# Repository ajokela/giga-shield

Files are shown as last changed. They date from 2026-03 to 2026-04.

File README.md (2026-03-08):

# Arduino Giga R1 WiFi Shield - Driven Level Shifter Redesign

## Overview

This is a redesigned shield/daughter board for the **Arduino Giga R1 WiFi** that replaces the original TXB0108PW auto-sensing bidirectional level translators with **SN74LVC8T245PW** driven (direction-controlled) level shifters.

The board provides 72 channels of 3.3V-to-5V level shifting across 9 ICs, mapping the Giga's 3.3V GPIO signals to 5V-compatible headers suitable for interfacing with retro hardware such as the Z80 CPU via a RetroShield.

## Why the Redesign

The original board used **TXB0108PW** auto-sensing bidirectional level translators. While convenient (no direction pin needed), the auto-sensing mechanism fails during Z80 bus cycles when signals are tri-stated. During these periods, the TXB0108 cannot determine the correct drive direction, causing the Arduino to be completely blind to certain Z80 execution states. This makes reliable bus monitoring and intervention impossible.

The **SN74LVC8T245PW** is a driven (explicit direction control) 8-bit dual-supply bus transceiver. The DIR pin explicitly sets the translation direction:
- **DIR LOW** = A-port to B-port (3.3V to 5V)
- **DIR HIGH** = B-port to A-port (5V to 3.3V)

This eliminates the ambiguity during tri-state periods and gives the Arduino full control over when it's reading vs. writing the bus.

## Board Specifications

| Parameter | Value |
|---|---|
| Dimensions | 155mm x 90mm |
| Layers | 2 (top + bottom copper) |
| Level Shifters | 9x SN74LVC8T245PW (TSSOP-24) |
| Decoupling Caps | 27x 0.1uF ceramic (0603) |
| DIR Pull-downs | 9x 10K resistor (0603) |
| Connectors | 10x pin headers (J1-J10) + 1x DIR control (J11) |
| Mounting Holes | 4x 3.2mm |
| Traces | 1843 |
| Vias | 158 |

## Signal Mapping

Each SN74LVC8T245PW translates 8 signals between the Giga's 3.3V domain (A-port) and the 5V headers (B-port).

### U1 - SCL/SDA/D9-D13
| A-Port (3.3V) | B-Port (5V) | Function |
|---|---|---|
| SCL1 | PB6 | I2C Clock |
| SDA1 | PH12 | I2C Data |
| AREF_3V3 | AREF | Analog Reference |
| D13 | PH6 | Digital 13 |
| D12 | PJ11 | Digital 12 |
| D11 | PJ10 | Digital 11 |
| D10 | PK1 | Digital 10 |
| D9 | PB9 | Digital 9 |

### U2 - Analog A0-A7
| A-Port (3.3V) | B-Port (5V) | Function |
|---|---|---|
| PC4 | A0 | Analog 0 |
| PC5 | A1 | Analog 1 |
| PB0 | A2 | Analog 2 |
| PB1 | A3 | Analog 3 |
| PC3 | A4 | Analog 4 |
| PC2 | A5 | Analog 5 |
| PC0 | A6 | Analog 6 |
| PA0 | A7 | Analog 7 |

### U3 - Digital D1-D8
| A-Port (3.3V) | B-Port (5V) | Function |
|---|---|---|
| D8 | PB8 | Digital 8 |
| D7 | PB4 | Digital 7 |
| D6 | PD13_5V | Digital 6 |
| D5 | PA7 | Digital 5 |
| D4 | PJ8 | Digital 4 |
| D3 | PA2 | Digital 3 |
| D2 | PA3 | Digital 2 |
| D1 | PA9 | Digital 1 |

### U4 - Analog A8-A11, DAC, CAN
| A-Port (3.3V) | B-Port (5V) | Function |
|---|---|---|
| PC2_C | A8 | Analog 8 |
| PC3_C | A9 | Analog 9 |
| PA1_C | A10 | Analog 10 |
| PA0_C | A11 | Analog 11 |
| PA4 | DAC0 | DAC Channel 0 |
| PA5 | DAC1 | DAC Channel 1 |
| PB5 | CAN_RX | CAN Bus RX |
| PB13 | CAN_TX | CAN Bus TX |

### U5 - Digital D0, D14-D20
| A-Port (3.3V) | B-Port (5V) | Function |
|---|---|---|
| D0 | PB7 | Digital 0 |
| D14 | PG14 | Digital 14 |
| D15 | PC7 | Digital 15 |
| D16 | PH13 | Digital 16 |
| D17 | PI9 | Digital 17 |
| D18 | PD5 | Digital 18 |
| D19 | PD6 | Digital 19 |
| D20 | PB11 | Digital 20 |

### U6 - Digital Even D22-D36
| A-Port (3.3V) | B-Port (5V) | Function |
|---|---|---|
| D22 | PJ12 | Digital 22 |
| D24 | PG12 | Digital 24 |
| D26 | PJ14 | Digital 26 |
| D28 | PJ15 | Digital 28 |
| D30 | PK3 | Digital 30 |
| D32 | PK4 | Digital 32 |
| D34 | PK5 | Digital 34 |
| D36 | PK6 | Digital 36 |

### U7 - Digital Odd D37-D51
| A-Port (3.3V) | B-Port (5V) | Function |
|---|---|---|
| D37 | PJ6 | Digital 37 |
| D39 | PI14 | Digital 39 |
| D41 | PK7 | Digital 41 |
| D43 | PI10 | Digital 43 |
| D45 | PI13 | Digital 45 |
| D47 | PB2 | Digital 47 |
| D49 | PE4 | Digital 49 |
| D51 | PE5 | Digital 51 |

### U8 - Digital Odd D21-D35
| A-Port (3.3V) | B-Port (5V) | Function |
|---|---|---|
| D21 | PH4 | Digital 21 |
| D23 | PG13 | Digital 23 |
| D25 | PJ0 | Digital 25 |
| D27 | PJ1 | Digital 27 |
| D29 | PJ2 | Digital 29 |
| D31 | PJ3 | Digital 31 |
| D33 | PJ4 | Digital 33 |
| D35 | PJ5 | Digital 35 |

### U9 - Digital Even D38-D52
| A-Port (3.3V) | B-Port (5V) | Function |
|---|---|---|
| D38 | PJ7 | Digital 38 |
| D40 | PE6 | Digital 40 |
| D42 | PI15 | Digital 42 |
| D44 | PG10 | Digital 44 |
| D46 | PH15 | Digital 46 |
| D48 | PK0 | Digital 48 |
| D50 | PI11 | Digital 50 |
| D52 | PK2 | Digital 52 |

## DIR Control (J11)

The J11 header provides per-shifter direction control. Each pin corresponds to one SN74LVC8T245PW's DIR input. A **10K pull-down resistor** on each DIR line defaults the direction to **A-to-B (3.3V to 5V)**.

| J11 Pin | Signal | Controls |
|---|---|---|
| 1 | DIR_U1 | U1 (SCL/SDA/D9-D13) |
| 2 | DIR_U2 | U2 (A0-A7) |
| 3 | DIR_U3 | U3 (D1-D8) |
| 4 | DIR_U4 | U4 (A8-A11/DAC/CAN) |
| 5 | DIR_U5 | U5 (D0/D14-D20) |
| 6 | DIR_U6 | U6 (Even D22-D36) |
| 7 | DIR_U7 | U7 (Odd D37-D51) |
| 8 | DIR_U8 | U8 (Odd D21-D35) |
| 9 | DIR_U9 | U9 (Even D38-D52) |
| 10 | GND | Ground reference |

To change a shifter's direction to **B-to-A (5V to 3.3V)**, drive the corresponding J11 pin HIGH (3.3V). This is done by running jumper wires from available Giga GPIO pins to the J11 header. Software then controls direction by toggling those GPIOs.

## Connectors

| Ref | Type | Pins | Location | Function |
|-----|---|---|---|---|
| J1 | 1x8 | 8 | Bottom edge | Giga 3.3V analog header |
| J2 | 1x10 | 10 | Top edge | Giga 3.3V header (power/analog ext) |
| J3 | 1x8 | 8 | Bottom edge | Giga 3.3V digital D1-D8 |
| J4 | 1x8 | 8 | Top edge | Giga 3.3V digital SCL/SDA/D9-D13 |
| J5 | 1x26 | 26 | Bottom edge | 5V analog header (J_ANALOG) |
| J6 | 1x8 | 8 | Bottom edge | Giga 3.3V digital D0/D14-D20 |
| J7 | 1x8 | 8 | Top edge | Giga 3.3V D21 + misc |
| J8 | 1x26 | 26 | Top edge | 5V digital header (J_DIGITAL) |
| J9 | 2x18 | 36 | Right side | 3.3V side connector (JSIDE) |
| J10 | 2x18 | 36 | Right side | 5V side connector (JSIDE_5V) |
| J11 | 1x10 | 10 | Center-left | DIR control header |

## Design Toolchain

The original board was designed in **KiCad 9.0** (file version 20241229). Since pcb-rnd 3.1.4 cannot read KiCad 9.0 files (version too new), the board was rebuilt from scratch using a Python generator script.

### Tools Used

| Tool | Version | Purpose |
|---|---|---|
| KiCad | 9.0.6 | Original design source, position/netlist reference |
| pcb-rnd | 3.1.4 | PCB format, DSN export, gerber/PNG export |
| Freerouting | 1.9.0 | Specctra-based autorouter |
| Python | 3.x | Board generator script (`build_giga_shield.py`) |

### Build Pipeline

1. **`build_giga_shield.py`** generates `giga_shield.pcb` with all components placed, footprints defined, and netlist specified in pcb-rnd native format
2. **pcb-rnd** exports the unrouted board to Specctra DSN format (`giga_shield.dsn`)
3. **Freerouting** reads the DSN, autoroutes all nets, and outputs a Specctra session file (`giga_shield.ses`)
4. **`ses_to_pcb.py`** imports the routed traces from the SES file back into the PCB
5. **pcb-rnd** exports final gerbers, drill files, and photo-realistic PNG renderings

### Key Implementation Details

- Component positions were extracted from the original KiCad PCB and translated from KiCad's coordinate origin (x=106mm, y=30.5mm) to pcb-rnd's (0,0) origin using the `kpos()` function
- All 1x pin headers are rotated 90 degrees to run horizontally along the board edges, matching the original KiCad layout (the Arduino Giga shield form factor has edge-parallel headers)
- TSSOP-24 footprints are generated programmatically with correct 0.65mm pitch, 6.4mm pad-to-pad span
- The SN74LVC8T245PW pin mapping was carefully verified against the datasheet: pins 1-12 on the left (DIR, A1-A4, GND, A5-A8, OE#, GND) and pins 13-24 on the right (B8-B5, VCCB, B4-B1, VCCA, VCCA, VCCB)
- OE# (pin 11) is tied to GND on all shifters (always enabled)
- Each shifter has two 0.1uF decoupling caps: one on VCCA (3.3V) and one on VCCB (5V)
- An additional 9 decoupling caps are placed along the bottom edge for power rail filtering

## SN74LVC8T245PW vs TXB0108PW

| Feature | TXB0108PW (Original) | SN74LVC8T245PW (New) |
|---|---|---|
| Package | TSSOP-20 | TSSOP-24 |
| Channels | 8 | 8 |
| Direction | Auto-sensing | Explicit DIR pin |
| A-Port Voltage | 1.2V - 3.6V | 1.2V - 3.6V |
| B-Port Voltage | 1.65V - 5.5V | 1.65V - 5.5V |
| Max Data Rate | 100 Mbps | 380 Mbps |
| Tri-state Handling | Unreliable | Deterministic |
| Output Enable | OE (active low) | OE# (active low) |
| Extra Pins | None | DIR control |

## Files

| File | Description |
|---|---|
| `build_giga_shield.py` | Python script that generates the entire PCB from scratch |
| `giga_shield.pcb` | Final routed PCB in pcb-rnd format |
| `giga_shield.dsn` | Specctra DSN export for autorouting |
| `giga_shield.ses` | Specctra session file with routing solution |
| `giga_shield_bom.csv` | Bill of materials |
| `giga_shield_centroid.csv` | Pick-and-place centroid file (SMD components) |
| `giga_shield_gerbers.zip` | Production files (gerbers + BOM + centroid) |
| `giga_shield_top.png` | Photo-realistic top view rendering |
| `giga_shield_bottom.png` | Photo-realistic bottom view rendering |
| `sn74lvc8t245_pinout.txt` | SN74LVC8T245 pinout reference |
| `kicad_source/` | Original KiCad 9.0 design files (reference) |
| `kicad_source/AlexJ_bz_ArduinoGigaShield.kicad_pcb` | Original KiCad PCB |
| `kicad_source/AlexJ_bz_ArduinoGigaShield.kicad_sch` | Original KiCad schematic |
| `kicad_source/AlexJ_bz_ArduinoGigaShield.pdf` | Original schematic PDF |
| `kicad_source/giga_pos.csv` | Component positions exported from KiCad |
| `kicad_source/giga_netlist.d356` | IPC-D-356 netlist exported from KiCad |

## Board Renderings

### Top
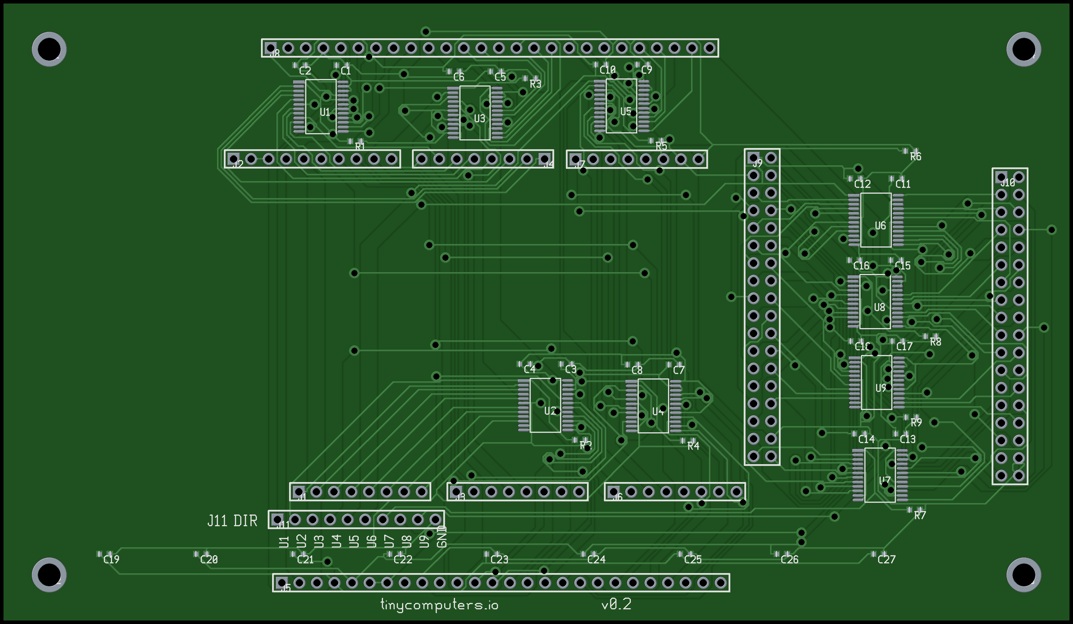
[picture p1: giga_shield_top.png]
Top View


### Bottom
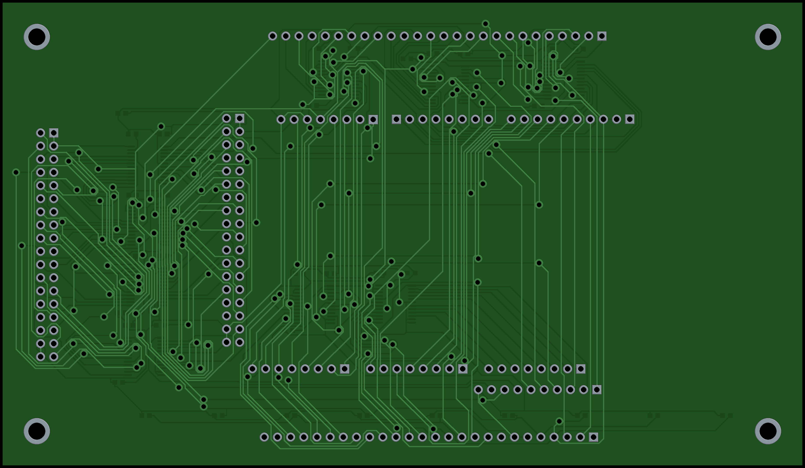
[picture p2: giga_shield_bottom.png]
Bottom View


## Development Notes

This section documents the full development process, including toolchain issues, format debugging, and workarounds encountered during the redesign.

### Starting Point

The original design (`AlexJ_bz_ArduinoGigaShield.kicad_pcb`) was created in **KiCad 9.0** (internal file version 20241229) with 9x TXB0108PW auto-sensing level shifters. The goal was to convert this to pcb-rnd format, swap in SN74LVC8T245PW driven shifters, and produce a fully routed production board.

### KiCad 9.0 to pcb-rnd Conversion Failure

pcb-rnd 3.1.4 includes an `io_kicad` plugin for reading KiCad files, but it only supports older KiCad versions. Attempting to open the KiCad 9.0 PCB produced:

```
unexpected layout version number (perhaps too new)
```

This was a hard blocker — there is no format converter from KiCad 9.0 to pcb-rnd.

### Extracting Data from KiCad

Since direct conversion was impossible, component positions and netlist data were extracted from KiCad using available tools:

1. **Component positions** were exported using `kicad-cli`:
   ```
   kicad-cli pcb export pos AlexJ_bz_ArduinoGigaShield.kicad_pcb -o giga_pos.csv
   ```

2. **Netlist/connectivity** was exported via IPC-D-356:
   ```
   kicad-cli pcb export ipc2581 ... -o giga_netlist.d356
   ```

3. **Signal mappings** (which Giga pin connects to which 5V header pin through which shifter) were extracted by parsing the KiCad schematic file (`AlexJ_bz_ArduinoGigaShield.kicad_sch`), which uses an s-expression format with positional net connections across hierarchical sheets.

### Building the Board from Scratch

With positions and netlist in hand, `build_giga_shield.py` was written to generate the entire pcb-rnd board programmatically. This script:

- Converts KiCad coordinates to pcb-rnd coordinates (KiCad origin at x=106mm, y=30.5mm; pcb-rnd at 0,0) using:
  ```python
  KX, KY = 106.0, 30.5
  def kpos(kx, ky):
      return (mm(kx - KX), mm(ky - KY))
  ```
- Generates TSSOP-24 footprints for the SN74LVC8T245PW (0.65mm pitch, 6.4mm pad-to-pad span, 24 pins with correct pin naming)
- Creates 0603 SMD footprints for decoupling caps and pull-down resistors
- Creates through-hole pin header footprints with rotation support
- Builds the complete netlist mapping all 72 signal channels across 9 shifters
- Outputs a valid pcb-rnd `.pcb` file

### pcb-rnd Format Debugging

Getting pcb-rnd to accept the generated file required solving several format issues. pcb-rnd's parser error messages were often unhelpful — errors in element definitions would sometimes be reported at a much later line (e.g., the outline layer starting at line 959).

**Issue 1: Element `"smd"` flag**

```
Element["smd" "TSSOP24" "U1" ...]
```
pcb-rnd rejected this with `Unknown flag: smd ignored`, which cascaded into a parse failure. The fix was to use an empty string for the first field:
```
Element["" "TSSOP24" "U1" ...]
```

**Issue 2: Bare `0` without unit suffix**

Mixed use of `0` and `0nm` in coordinate values caused silent parse errors:
```
Pin[0 0 1700000nm ...]    # WRONG - bare 0
Pin[0nm 0nm 1700000nm ...]  # CORRECT
```
All zero values needed the explicit `nm` suffix for consistency.

**Issue 3: Layer `Line[]` missing flags argument**

The `Line[]` entry inside Layer blocks requires 7 fields, but the generator was only outputting 6 (omitting the flags string):
```
Line[x1 y1 x2 y2 thickness clearance]           # WRONG - 6 fields
Line[x1 y1 x2 y2 thickness clearance "clearline"]  # CORRECT - 7 fields
```
The error was `syntax error, unexpected ']', expecting INTEGER or STRING`, which appeared at the outline layer rather than at the actual problematic line.

**Debugging technique: Binary search with file truncation**

Since pcb-rnd always reported the error at the same line regardless of where the actual issue was, a binary search approach was used — progressively truncating the file with `head -N` to isolate which section introduced the parse failure:
```
head -100 giga_shield.pcb > test.pcb && pcb-rnd -x png test.pcb  # OK → mounting holes fine
head -300 giga_shield.pcb > test.pcb && pcb-rnd -x png test.pcb  # OK → connectors fine
head -500 giga_shield.pcb > test.pcb && pcb-rnd -x png test.pcb  # OK → shifters fine
head -700 giga_shield.pcb > test.pcb && pcb-rnd -x png test.pcb  # OK → all elements fine
head -960 giga_shield.pcb > test.pcb && pcb-rnd -x png test.pcb  # FAIL → layers are the problem
```
This narrowed the issue to the Layer blocks, where the missing flags argument was found.

### Connector Rotation

The initial build placed all pin headers with pins extending downward (+Y). For the Arduino Giga shield form factor, the long 1x headers actually run horizontally along the board edges. Without rotation, J5 (1x26 at y=84mm) extended 63.5mm downward to y=148mm — well past the 90mm board edge. J11 (1x10 at y=75mm) similarly extended to y=98mm.

The fix involved:
1. Extracting rotation angles from the original KiCad PCB — all 1x headers had 90° or -90° rotation
2. Adding a `rot` parameter to `pin_header_element()` with a rotation transform:
   ```python
   def rotate(px, py):
       if rot == 90:     # KiCad 90° → pins extend in +X
           return (py, -px)
       elif rot == -90:  # KiCad -90° → pins extend in -X
           return (-py, px)
       return (px, py)
   ```
3. Applying rotation to both pin coordinates and element outlines

After rotation, all connectors fit within the board:
- J5 (1x26): x=[40.6, 104.1], y=84.2 — runs along the bottom edge
- J8 (1x26): x=[39.0, 102.5], y=6.8 — runs along the top edge
- J11 (1x10): x=[40.0, 62.9], y=75.0 — runs horizontally on the board

### Remote Toolchain

pcb-rnd is not readily available on macOS. All pcb-rnd operations (DSN export, gerber generation, PNG rendering) were performed on a remote Linux machine via SSH:

```bash
# Upload PCB
scp giga_shield.pcb alex@192.168.0.219:/tmp/

# Export DSN for autorouting
ssh alex@192.168.0.219 'cd /tmp && pcb-rnd -x dsn giga_shield.pcb'

# Export gerbers
ssh alex@192.168.0.219 'cd /tmp && pcb-rnd -x gerber giga_shield.pcb'

# Render photo-realistic PNG (600 DPI, green solder mask, gold plating)
ssh alex@192.168.0.219 'pcb-rnd -x png --dpi 600 --photo-mode --outfile top.png giga_shield.pcb'
ssh alex@192.168.0.219 'pcb-rnd -x png --dpi 600 --photo-mode --photo-flip-y --outfile bottom.png giga_shield.pcb'

# Download results
scp alex@192.168.0.219:/tmp/giga_shield.*.gbr .
scp alex@192.168.0.219:/tmp/top.png giga_shield_top.png
```

### Autorouting Pipeline

The routing pipeline uses Specctra DSN/SES interchange format as the bridge between pcb-rnd and Freerouting:

```
giga_shield.pcb → [pcb-rnd DSN export] → giga_shield.dsn
                                               ↓
                                    [Freerouting autorouter]
                                         (~55 minutes)
                                               ↓
giga_shield.pcb ← [ses_to_pcb.py]  ← giga_shield.ses
```

**Freerouting** (v1.9.0) is a Java-based Specctra autorouter:
```bash
java -jar freerouting-1.9.0.jar -de giga_shield.dsn -do giga_shield.ses -mp 60
```
The `-mp 60` flag sets 60 optimization passes. A typical run takes ~55 minutes and produces optimized routing with ~1843 traces and ~158 vias.

**`ses_to_pcb.py`** parses the Freerouting SES output and injects `Line[]` entries (traces) and `Via[]` entries into the pcb-rnd PCB file's Layer blocks.

**`strip_traces.py`** removes all routed traces and autorouted vias from a PCB file, leaving only components and netlist — used to prepare for re-routing after component moves. It identifies autorouted vias by their 914400nm pad size (the default from `ses_to_pcb.py`).

Both helper scripts originate from the [dual-z80](https://github.com/ajokela/dual-z80) project.

### Reproduction Steps

To rebuild the board from scratch:

```bash
# 1. Generate the unrouted PCB
python3 build_giga_shield.py giga_shield.pcb

# 2. Export DSN (on a machine with pcb-rnd installed)
pcb-rnd -x dsn giga_shield.pcb

# 3. Run Freerouting (~55 minutes)
java -jar freerouting-1.9.0.jar -de giga_shield.dsn -do giga_shield.ses -mp 60

# 4. Import routes back into PCB
python3 ses_to_pcb.py giga_shield.ses giga_shield.pcb

# 5. Export gerbers
pcb-rnd -x gerber giga_shield.pcb

# 6. Render board images
pcb-rnd -x png --dpi 600 --photo-mode --outfile giga_shield_top.png giga_shield.pcb
pcb-rnd -x png --dpi 600 --photo-mode --photo-flip-y --outfile giga_shield_bottom.png giga_shield.pcb
```

To re-route after component changes:
```bash
# Strip existing traces
python3 strip_traces.py giga_shield.pcb

# Then repeat steps 2-6 above
```

## License

BSD 3-Clause License

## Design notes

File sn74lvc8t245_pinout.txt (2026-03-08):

SN74LVC8T245PW (TSSOP-24) Pinout:
Pin 1:  1DIR    (Direction control: LOW=A→B, HIGH=B→A)
Pin 2:  A1
Pin 3:  A2
Pin 4:  A3
Pin 5:  A4
Pin 6:  GND
Pin 7:  A5
Pin 8:  A6
Pin 9:  A7
Pin 10: A8
Pin 11: 1OE#    (Output Enable, active LOW)
Pin 12: GND
Pin 13: B8
Pin 14: B7
Pin 15: B6
Pin 16: B5
Pin 17: VCCB    (5V side power)
Pin 18: B4
Pin 19: B3
Pin 20: B2
Pin 21: B1
Pin 22: VCCA    (3.3V side power)
Pin 23: VCCA
Pin 24: VCCB

TXB0108PW (TSSOP-20) Pinout (current):
Pin 1:  VCCA    (3.3V side power)
Pin 2:  A1
Pin 3:  A2
Pin 4:  A3
Pin 5:  A4
Pin 6:  A5
Pin 7:  A6
Pin 8:  A7
Pin 9:  A8
Pin 10: GND
Pin 11: OE      (Output Enable, active HIGH)
Pin 12: B8
Pin 13: B7
Pin 14: B6
Pin 15: B5
Pin 16: B4
Pin 17: B3
Pin 18: B2
Pin 19: B1
Pin 20: VCCB    (5V side power)

Key differences:
- SN74LVC8T245 has 24 pins (4 more: extra GND, extra VCC, DIR, split VCCA)
- DIR pin added (pin 1) - this is the key feature
- OE is active LOW on SN74LVC8T245 (vs active HIGH on TXB0108)
- A5-A8 shifted by one position due to extra GND at pin 6
- B-side pins similar but shifted
- Dual VCCA pins (22,23) and dual VCCB pins (17,24)

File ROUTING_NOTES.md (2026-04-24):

# Giga Shield v0.3: Routing Journey

Notes for a future blog post. Covers everything tried to get a fully-routed 6-layer level shifter board.

## The Board

Arduino Giga R1 WiFi shield with 10x SN74LVC8T245PW driven level shifters (TSSOP-24). Replaces the original TXB0108PW auto-sensing design, which fails during Z80 bus tri-state periods. 155mm x 90mm, 80 channels of 3.3V/5V level shifting, 161 nets, 39 SMD components, 10+ through-hole connectors.

## The Core Problem: GND

The board has 72 GND pads across 10 TSSOP-24 ICs (pins 6, 11, 12 on each), 29 decoupling caps, and 10 pull-down resistors. In a normal KiCad workflow, you'd route signals and then flood the board with a GND copper pour. Freerouting (the open-source Specctra autorouter) cannot do copper pours. It treats every net, including GND, as point-to-point traces.

The TSSOP-24 package makes this worse. At 0.65mm pitch, there's only ~0.25mm between pad edges. A via needs ~0.9mm diameter (drill + annular ring + clearance). There is physically no room to place a via next to a TSSOP-24 GND pad without violating DRC. Freerouting reports "via mask not found for net" and leaves GND connections unrouted.

## The Toolchain

The board was designed entirely in Python. `build_giga_shield.py` generates a pcb-rnd native `.pcb` file from scratch, with all component positions, footprints, and netlists defined programmatically. Component positions were extracted from an earlier KiCad 9.0 design, but pcb-rnd 3.1.4 can't read KiCad 9.0 files, so everything was regenerated.

The routing pipeline:
```
build_giga_shield.py -> giga_shield.pcb
                           |
                    pcb-rnd DSN export
                           |
                    giga_shield.dsn
                           |
                    Freerouting 1.9.0
                           |
                    giga_shield.ses
                           |
                    ses_to_pcb.py -> routed giga_shield.pcb
```

pcb-rnd runs on a remote Linux machine (10.1.1.27, Ryzen AI MAX+ 395) via SSH since it's not available on macOS.

## Attempt 1: 2-Layer with Freerouting

The simplest approach. Exclude GND from routing, let freerouting handle all signal and power nets on 2 layers, then add GND connections afterward.

**Config:**
```python
POWER_NETS = {'GND', 'VIN'}  # excluded from routing
```

Freerouting 1.9.0 with `-mp 100` (100 optimization passes). Single run: ~55 minutes. Result: 6 unrouted nets on the best run. The remaining 6 were always signal traces boxed in by other routes with no path to their destination.

**Verdict:** Close but not clean. 6 unrouted is 6 too many for production.

## Attempt 2: Manual GND Post-Processing (add_gnd.py)

Wrote a script to add GND after routing. Strategy:
1. Calculate exact GND pad positions from component geometry
2. Place a via near each SMD GND pad (offset ~0.5mm to avoid other pads)
3. Connect all vias on the bottom layer using a Minimum Spanning Tree (Prim's algorithm)

The MST approach minimizes total trace length while connecting all 72+ GND points. IC GND pads get vias offset to the left (away from IC body), cap/resistor pads get vias offset downward.

**Problem:** The vias still couldn't fit in the 0.65mm pitch gaps between TSSOP-24 pads. Even with the offset, they collided with adjacent signal pads. The script produced a connected GND network but with DRC violations everywhere.

**Verdict:** Clever but geometry wins. Can't squeeze a 0.9mm via into a 0.25mm gap.

## Attempt 3: Copper Pour + Stitching Vias (add_pours.py)

Instead of point-to-point GND traces, add a full copper polygon on the bottom layer and stitch it with vias:
- Full-board GND polygon on Layer 2 with 0.5mm edge margin
- 30 vias near IC GND pads (1.5mm offset from pad center)
- 20 vias near cap GND pads (1.2mm offset)
- Grid of stitching vias every 15mm across the board

**Problem:** pcb-rnd polygons in the native format don't have net assignment in the way that matters for DRC. The polygon existed but wasn't treated as part of the GND net by the autorouter or DRC checker. The GND pads were still electrically floating.

**Verdict:** pcb-rnd's polygon support isn't designed for this workflow.

## Attempt 4: 4-Layer Board

Added two inner layers: one for GND plane, one for power (+3V3/+5V). This is the "standard" solution for dense SMD boards.

**Config:**
```python
# 4 layers: top(1), GND(2), power(3), bottom(4), outline(5)
out.append('Groups("1,c:2:3:4,s:5")')
```

Freerouting still couldn't use the inner GND layer as a plane. It only does point-to-point routing. The extra layers gave more room for signal traces, but the fundamental GND problem remained. Best result: still 5-6 unrouted.

**Verdict:** More layers don't help when the tool can't do planes.

## Attempt 5: 6-Layer Board

Six copper layers: top, GND, signal, signal, GND, bottom.

Same fundamental limitation. Freerouting had more routing channels but still couldn't handle GND as a plane. Best result with 6 layers: 5 unrouted.

**Verdict:** Diminishing returns. The problem is the tool, not the layer count.

## Attempt 6: Massively Parallel Routing

The insight: freerouting converges to a local optimum. Different net ordering in the DSN file produces different initial routing solutions, which converge to different local optima. If you run enough parallel jobs, one might find the global optimum (0 unrouted).

### Net Shuffling (shuffle_dsn.py)

Wrote a script to generate N copies of the DSN file with randomized net ordering:
```python
random.seed(i * 31337 + 42)  # deterministic but different per copy
random.shuffle(shuffled_nets)
```

Generated 128+ shuffled copies. Each one routes nets in a different order, exploring a different region of the solution space.

### Infrastructure: 3 Machines

- **Local Mac** (M3 Max): 8 parallel jobs
- **10.1.1.24** (64-core, 4x Tesla P40): 64 parallel jobs
- **10.1.1.27** (32-core, Ryzen AI MAX+ 395): 64 parallel jobs

Total: 128+ simultaneous freerouting instances.

### Deployment Hurdles

**Java version mismatch.** Freerouting 1.9.0 was compiled targeting Java 24 (class file version 68.0). The servers had Java 21 (max class version 65.0). Error: `UnsupportedClassVersionError: class file version 68.0`. Fixed by modifying `freerouting/build.gradle`:
```groovy
// Changed from VERSION_24 to VERSION_21
sourceCompatibility = JavaVersion.VERSION_21
targetCompatibility = JavaVersion.VERSION_21
// Commented out java.toolchain block
```
Then rebuilt: `./gradlew executableV19Jar --no-configuration-cache`

**Gradle toolchain error.** `JvmVendorSpec IBM_SEMERU field not found` when building. Fixed by commenting out the entire `java.toolchain` block.

**X11 headless requirement.** Freerouting's GUI code initializes even in batch mode (`-de`, `-do` flags). On headless servers: `HeadlessException: No X11 DISPLAY variable was set`. Fix: install full JRE (`openjdk-21-jre`, not `-headless`) and use `xvfb-run -a` or a shared Xvfb display.

Two scripts for this:
- `run_batch.sh`: Single shared `Xvfb :99` display for all 64 jobs
- `run_batch_xvfb.sh`: `xvfb-run -a` per job (auto-allocated display numbers, more robust)

**Disk space on 10.1.1.27.** 1.9TB disk was at 100% (191GB old logs, large TTS wav files from previous projects). Had to clean up before jobs could write output.

**scp brace expansion.** `scp shuffled_runs/run_{000..031}.dsn user@host:` doesn't work on macOS zsh (brace expansion happens before scp processes the argument). Used `scp shuffled_runs/*.dsn` instead.

### Results: 2-Layer Parallel

Best result across 128 runs: **6 unrouted**. Multiple runs hit 6, none hit 0. The 2-layer board appears to have a hard floor around 6 unrouted nets.

### Results: 6-Layer Parallel

Best result: **5 unrouted**. Marginal improvement but still not clean.

### Freerouting 2.1.0: A Regression

Tried the newer Freerouting v2.1.0 hoping for better results. It was dramatically worse: **152+ unrouted** after 250 passes on the same 2-layer board where v1.9.0 hit 6. Immediately went back to v1.9.0.

**Verdict:** Massive parallelism finds better solutions but can't break through the fundamental floor. The problem is GND routing in TSSOP-24 pitch, and no amount of net shuffling fixes that.

## Attempt 7: Quilter.ai (The Winner)

Quilter.ai is an AI-powered PCB router. Uploaded the KiCad board (generated by `build_kicad.py`) to their service.

### What Quilter Produced

6-layer board, fully routed:
- **0 unrouted nets**
- 2,433 trace segments
- 334 vias
- 2 GND copper zones (on In1.Cu and In4.Cu)

Layer stackup:
| Layer | Purpose |
|---|---|
| F.Cu | Signals (top) |
| In1.Cu | GND plane |
| In2.Cu | Signals |
| In3.Cu | Signals |
| In4.Cu | GND plane |
| B.Cu | Signals (bottom) |

The key difference: Quilter understands copper zones. It placed GND planes on In1.Cu and In4.Cu, then used vias to connect TSSOP-24 GND pads down to the plane. This is the standard approach that freerouting simply cannot do.

### Verification

Exported the Quilter board's DSN and fed it back into freerouting to confirm: 0 unrouted, all nets complete.

Ran a signal integrity analysis:
- All 10 ICs' net assignments match the original design
- No bus contention (each Arduino pin maps to exactly one level shifter channel)
- Power integrity verified (GND, +3V3, +5V all correct)
- Direction control properly wired with pull-down resistors
- U9 has 6 NC spare pads, U10 has 8 NC spare pads (intentional; 80 GPIO don't divide evenly into 10x 8-channel ICs)

### Fabrication Output

Used KiCad CLI for fabrication files:
```bash
kicad-cli pcb export gerbers giga_shield_v03_final.kicad_pcb -o fabrication/
kicad-cli pcb export drill giga_shield_v03_final.kicad_pcb -o fabrication/
kicad-cli pcb export pos giga_shield_v03_final.kicad_pcb -o fabrication/giga_shield_v03_final_cpl.csv
```

13 Gerber files (6 copper + 2 solder mask + 2 silk + 2 paste + 1 edge cuts), drill file, pick-and-place CSV, and BOM. Packaged into `giga_shield_v03_gerbers.zip` (293KB) for PCBWay upload.

## Lessons Learned

1. **Freerouting can't do copper pours.** This is its biggest limitation for modern SMD boards. Any design with dense GND connections (which is basically every board with fine-pitch ICs) will struggle.

2. **TSSOP-24 at 0.65mm pitch is too tight for via-in-pad with freerouting's constraints.** The ~0.25mm gap between pads won't fit a via. The autorouter hits a hard geometric limit, not just a search problem.

3. **Net shuffling + parallel runs is a legitimate technique for exploring routing solution space.** Different net ordering produces meaningfully different results. But it can't overcome fundamental geometric constraints.

4. **Freerouting 1.9.0 >> 2.1.0** for this board, by a factor of 25x in terms of unrouted nets (6 vs 152+).

5. **Quilter.ai solved in one shot what 128+ parallel freerouting runs couldn't.** The difference is copper zone support, not routing algorithm cleverness. The right abstraction (planes) matters more than brute-force search.

6. **The open-source PCB toolchain has real gaps.** pcb-rnd can't read KiCad 9.0. Freerouting can't do copper pours. There's no open-source equivalent to Quilter.ai. For a hobbyist project, this meant writing hundreds of lines of Python glue code and custom post-processing scripts.

7. **Headless Java GUI apps are annoying.** Freerouting initializes Swing even in batch mode. xvfb-run works but adds deployment complexity to what should be a command-line tool.

8. **The Python-generated PCB approach is powerful.** Being able to regenerate the entire board programmatically made it easy to try different layer configurations, adjust component positions, and iterate rapidly. The build script is the single source of truth.

## Scripts Written

| Script | Purpose | Used in final? |
|---|---|---|
| `build_giga_shield.py` | Generate pcb-rnd board from Python | Yes (for pcb-rnd workflow) |
| `build_kicad.py` | Generate KiCad board from Python | Yes (input to Quilter) |
| `shuffle_dsn.py` | Randomize net order in DSN files | No (Quilter won) |
| `add_gnd.py` | MST-based GND routing post-processor | No (geometric limit) |
| `add_pours.py` | Copper pour + stitching vias | No (pcb-rnd polygon limitation) |
| `add_power_nets.py` | Inject +3V3/+5V nets into netlist | Yes (for pcb-rnd workflow) |
| `route_d15.py` | A* pathfinder for one stuck net | No (single-net fix attempt) |
| `run_batch.sh` | 64 parallel freerouting (shared Xvfb) | Yes (on remote servers) |
| `run_batch_xvfb.sh` | 64 parallel freerouting (xvfb-run) | Yes (on remote servers) |
| `ses_to_pcb.py` | Import freerouting results to pcb-rnd | Yes (for pcb-rnd workflow) |
| `strip_traces.py` | Remove routes for re-routing | Yes (for iteration) |

## Timeline

All of this happened in a single working session. From "let's run freerouting" to "fabrication package ready for PCBWay" took one extended session, with most of the time spent discovering freerouting's GND limitation, trying workarounds, scaling up parallel runs, and finally getting the clean result from Quilter.ai.

## Final BOM (39 SMD + 4 mounting holes)

| Qty | Part | Package | Value | MPN |
|-----|---|---|---|-----|
| 29 | Ceramic cap | 0603 | 100nF | GRM188R71C104KA01D |
| 10 | Resistor | 0603 | 10K | RC0603FR-0710KL |
| 10 | Level shifter | TSSOP-24 | SN74LVC8T245PW | SN74LVC8T245PW |
| 4 | Mounting hole | 3.2mm | - | - |

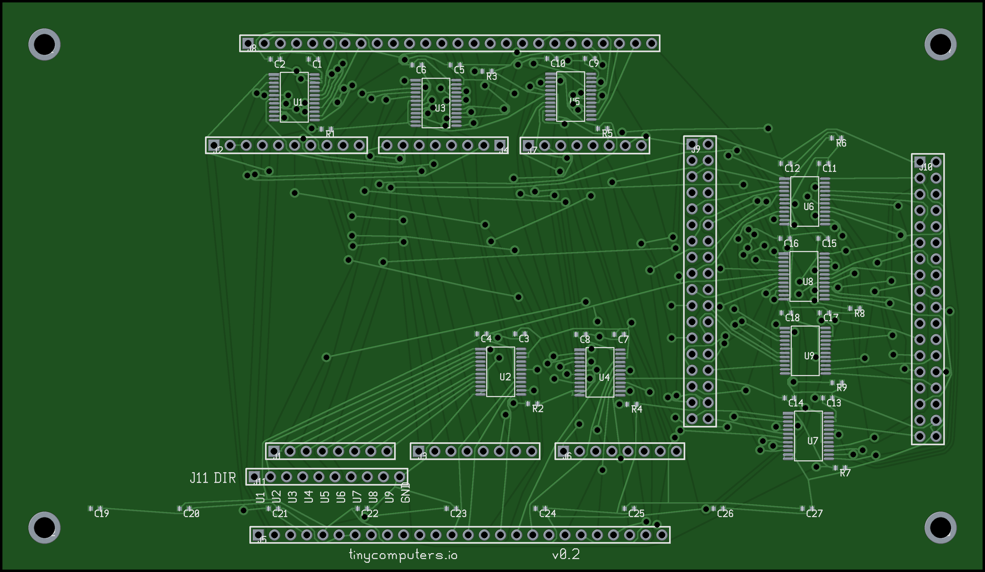
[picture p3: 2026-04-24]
giga_shield_freerouted_anyangle.png

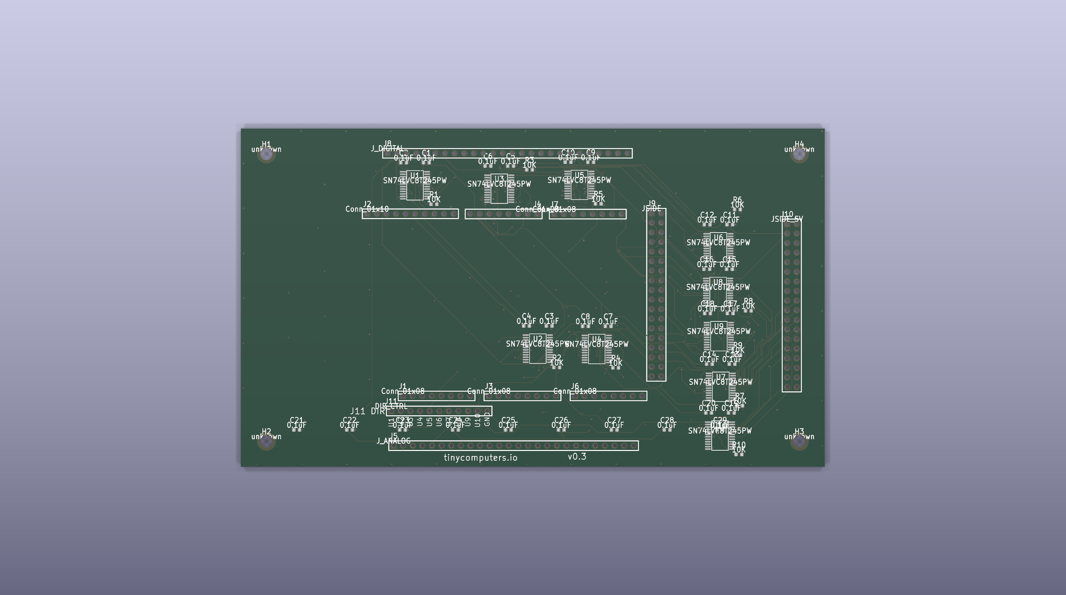
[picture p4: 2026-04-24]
giga_shield_v03_top.png

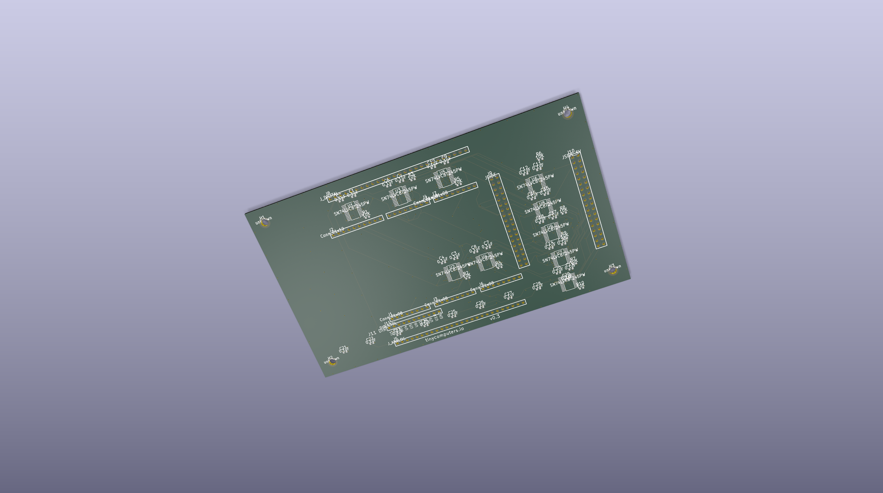
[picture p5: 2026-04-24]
giga_shield_v03_iso.png

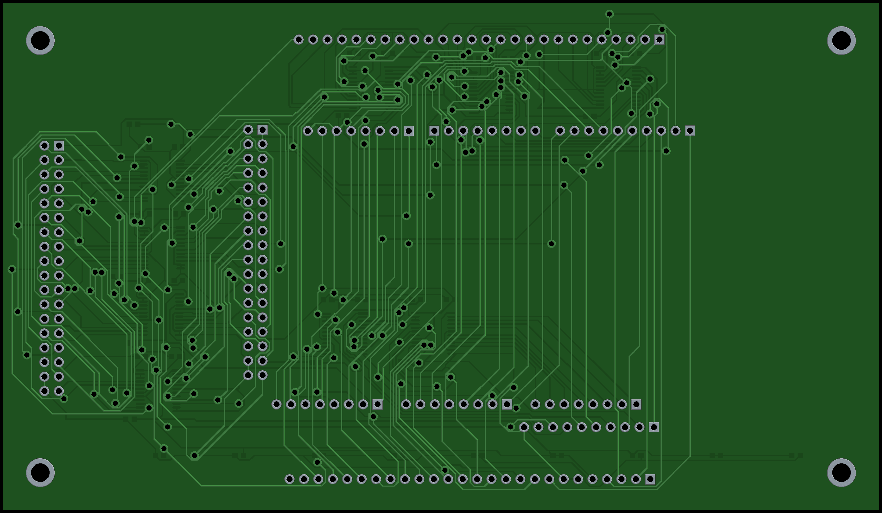
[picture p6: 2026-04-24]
giga_shield_freerouted_bottom.png

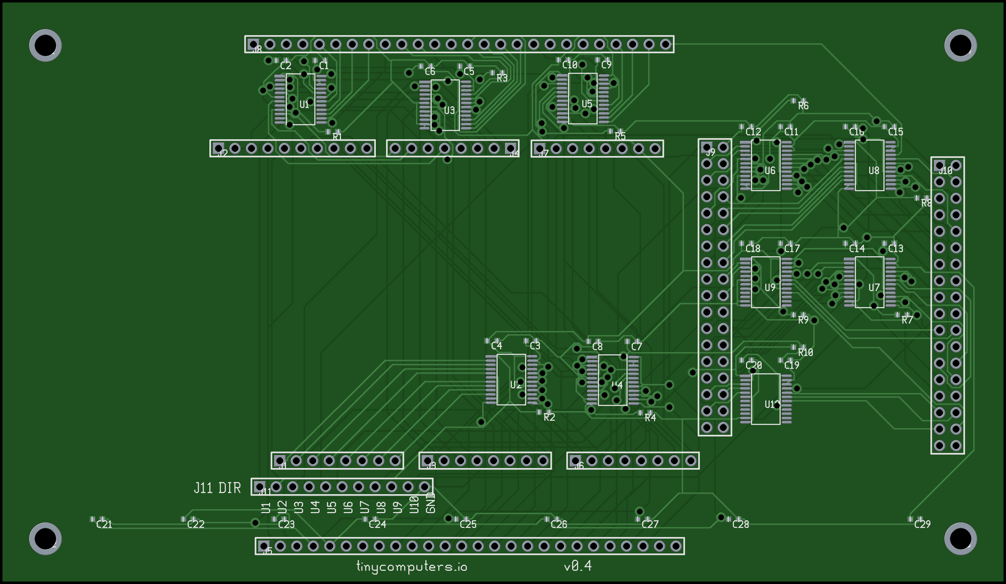
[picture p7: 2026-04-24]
giga_shield_v04_top.png

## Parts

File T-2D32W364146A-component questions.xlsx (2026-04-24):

 | T-2D32W364146A
序号 No. | 型号 Mfg Part | 规格 Description | 封装 Package | 位号 Designator | 异常类型 Material Counting | 客户回复 Customer Response | 不良图片 Bad Images
3 | GRM188R71C104KA01D | 0.1uF Extra +3V3 decoupling capacitor 100nF | 0603 | C21,C23,C25,C27,C29 | Pls check the pics. The pads of C29 and U10 conflict with each other. So we can't solder C29 and U10 in the meantime. So could you pls confirm we should solder which one this time? | Skip placing C29, please solder U10

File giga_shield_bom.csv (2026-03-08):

Qty | Description | Value | Package | RefDes | Manufacturer Part Number | Notes
9 | 8-Bit Dual-Supply Bus Transceiver with Direction Control | - | TSSOP-24 | U1 U2 U3 U4 U5 U6 U7 U8 U9 | SN74LVC8T245PW | Driven level shifter 3.3V<->5V
27 | Ceramic Capacitor | 0.1uF | 0603 | C1-C27 |  | Decoupling capacitors
9 | Resistor | 10K | 0603 | R1-R9 |  | DIR pin pull-down resistors (default A->B)

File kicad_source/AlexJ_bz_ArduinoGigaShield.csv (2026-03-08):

Reference | Qty | Value | Footprint | Mfr. PART # | SUPPLIER
C1,C2,C3,C4,C5,C6,C7,C8,C9,C10,C11,C12,C13,C14,C15,C16,C17,C18,C19,C20,C21,C22,C23,C24,C25,C26,C27 | 27 | 0.1uF | Capacitor_SMD:C_0603_1608Metric | CC0603KRX7R9BB104 | LCSC
J1,J3,J4,J6,J7 | 5 | Conn_01x08 | Connector_PinHeader_2.54mm:PinHeader_1x08_P2.54mm_Vertical | DNP | LCSC
J2 | 1 | Conn_01x10 | Connector_PinHeader_2.54mm:PinHeader_1x10_P2.54mm_Vertical | DNP | LCSC
J5,J8 | 2 | Conn_01x26 | Connector_PinHeader_2.54mm:PinHeader_1x26_P2.54mm_Vertical | DNP | LCSC
J9 | 1 | JSIDE | Connector_PinHeader_2.54mm:PinHeader_2x18_P2.54mm_Vertical | DNP | LCSC
J10 | 1 | JSIDE_5V | Connector_PinHeader_2.54mm:PinHeader_2x18_P2.54mm_Vertical | DNP | LCSC
R1,R2,R3,R4,R5,R6,R7,R8,R9 | 9 | 10K | Resistor_SMD:R_0603_1608Metric | RC0603FR-0710KL | LCSC
U1,U2,U3,U4,U5,U6,U7,U8,U9 | 9 | TXB0108PW | Package_SO:TSSOP-20_4.4x6.5mm_P0.65mm | TXB0108PWR | LCSC

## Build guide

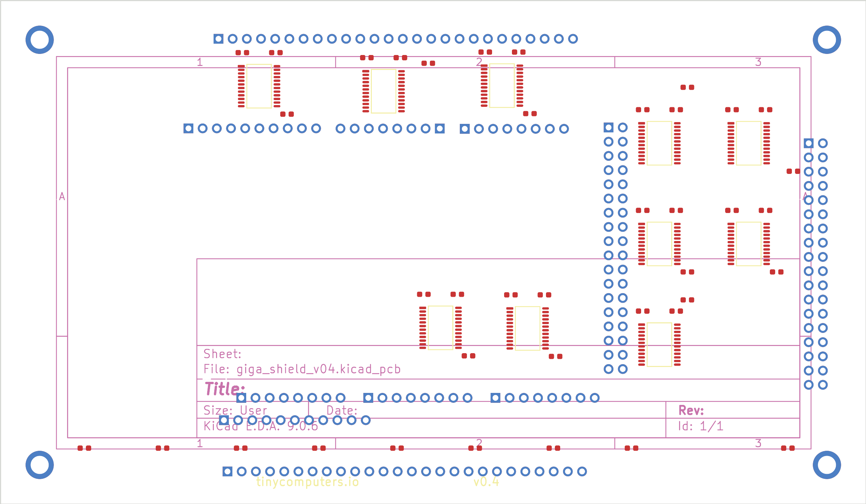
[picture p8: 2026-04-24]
benchmark/pyplacer/manual_compare.png

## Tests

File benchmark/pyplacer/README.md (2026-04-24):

# pyplacer

A simulated-annealing PCB component placer in ~500 lines of Python.

**Purpose:** Provide an open-source alternative to commercial ML placers (Quilter.ai) for
benchmark comparison with Freerouting. Takes a KiCad PCB file with components moved off-board
and produces a placed PCB file. Does not route — pair with Freerouting for that.

## Algorithm

Classic Kirkpatrick-style simulated annealing:

1. **Initial state**: random placement of movable components inside the board outline
   (fixed components — connectors and mounting holes — stay where they are).
2. **Cost function**: Half-Perimeter Wire Length (HPWL) over all nets + overlap penalty
   + out-of-bounds penalty.
3. **Moves**: translate, rotate (90° increments), or swap two components.
4. **Acceptance**: if ΔE ≤ 0 always accept; else accept with probability e^(-ΔE / T).
5. **Cooling**: exponential T ← αT with α ≈ 0.95, N moves per temperature plateau.
6. **Termination**: T below threshold or no improvement for K plateaus.

## Data model

Components are parsed from the `.kicad_pcb` file. Each has:
- reference designator
- position (x, y), rotation (0/90/180/270)
- pads with local coordinates and assigned nets
- local bounding box (for overlap check)
- fixed flag (connectors J*, mounting holes H*)

Nets are lists of (component_ref, pad_id) pairs from the file's net table.

## File I/O

Parses KiCad 9 format (version 20241229). The parser preserves everything except
footprint positions — we only rewrite the top-level `(at X Y [rot])` of each movable
footprint. Non-movable footprints and all other content pass through untouched.

## Usage

```bash
python3 run.py input.kicad_pcb output.kicad_pcb
```

Optional flags:
- `--iterations N` — number of SA moves per temperature (default 5000)
- `--t-init T` — initial temperature (default: auto from initial cost)
- `--cooling A` — cooling rate 0.0-1.0 (default 0.95)
- `--seed S` — random seed for reproducibility
- `--plot` — dump a PNG of the final placement

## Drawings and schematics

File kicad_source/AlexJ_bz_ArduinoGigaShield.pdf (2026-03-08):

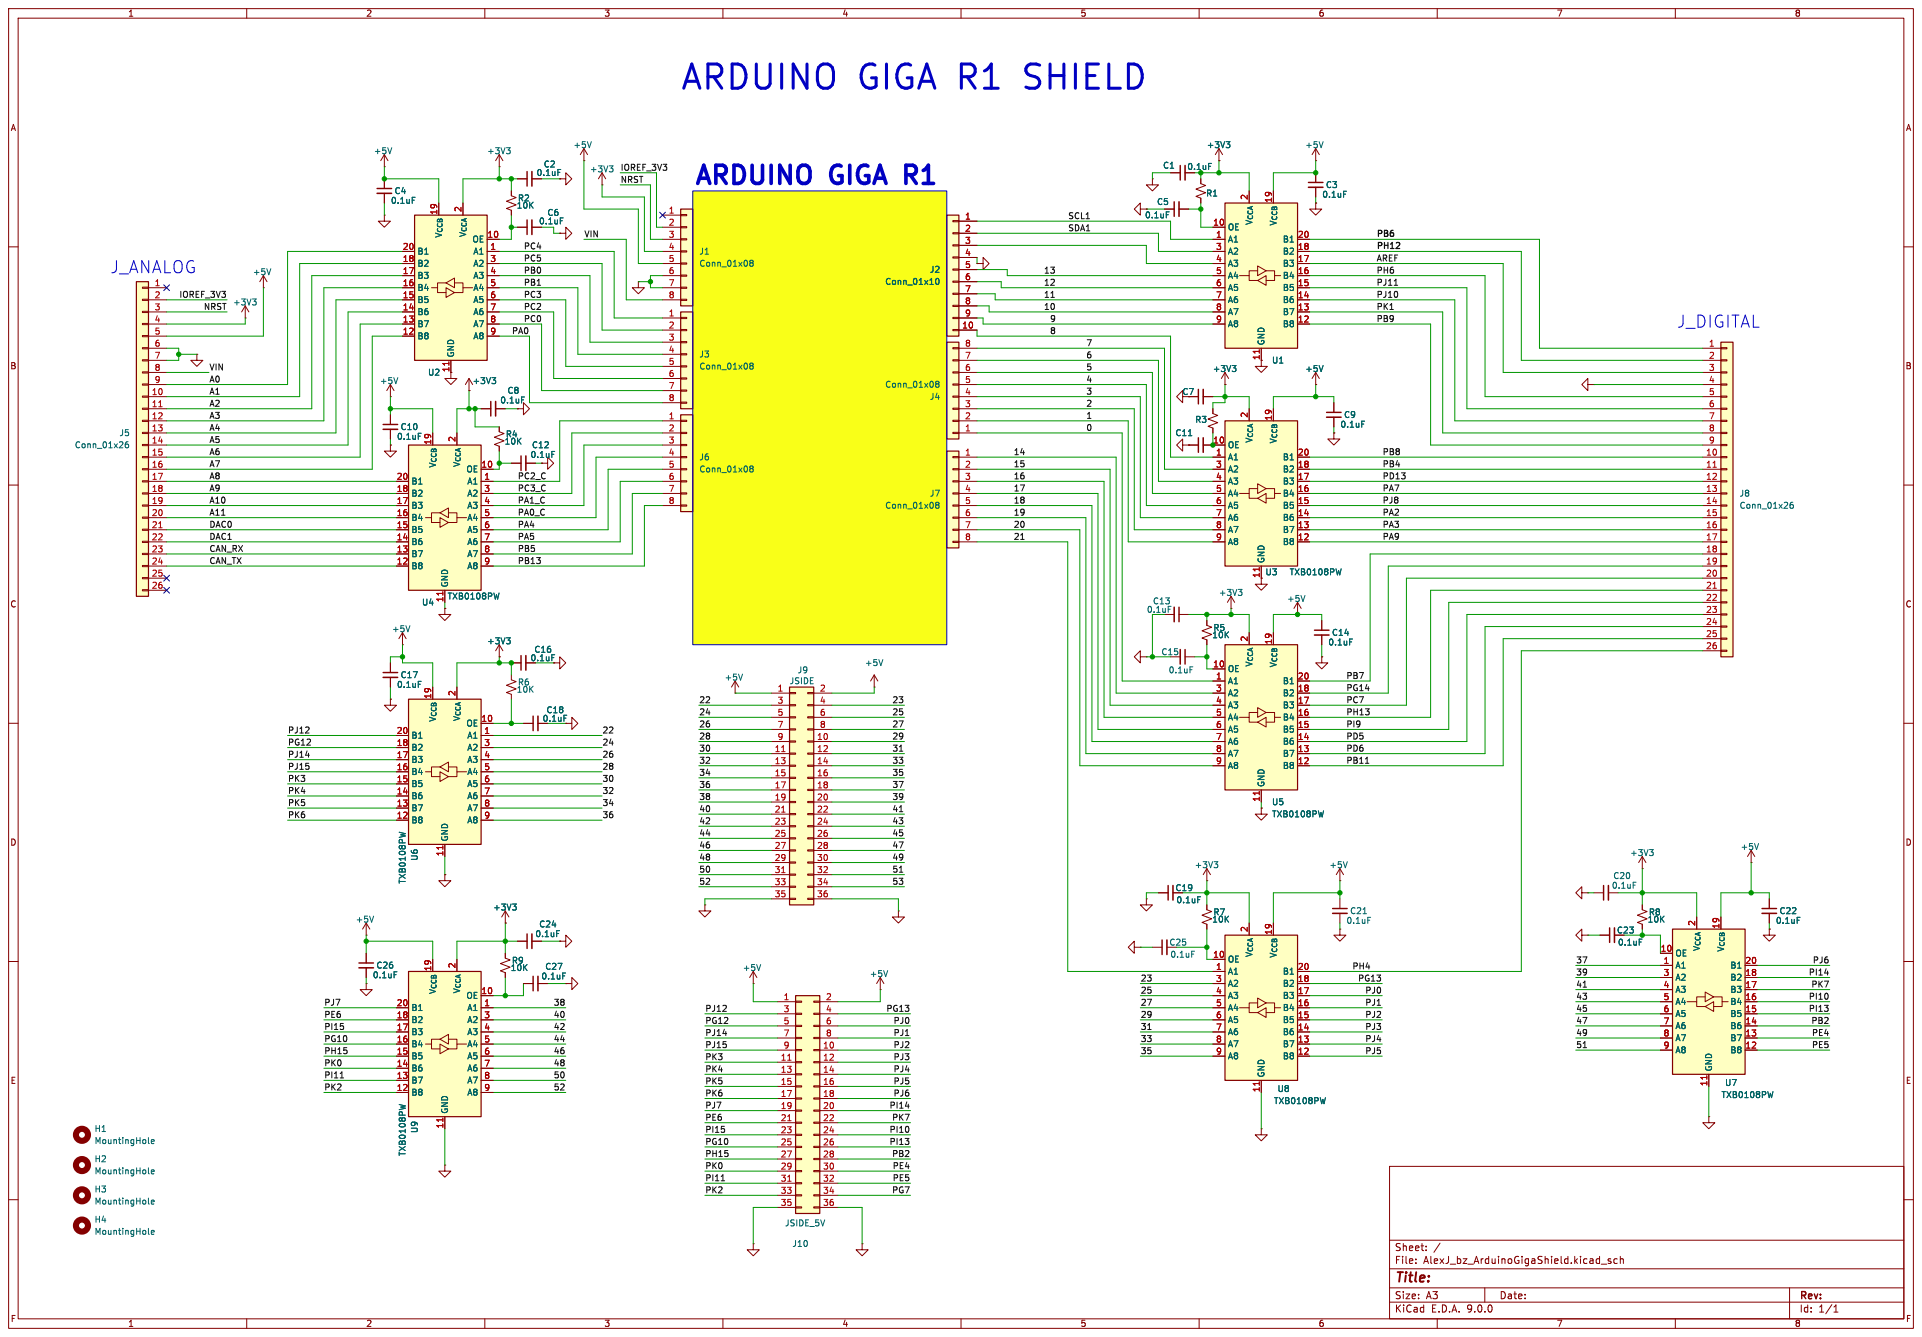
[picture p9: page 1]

OE 10 A1 1 A2 3 A3 4 A4 5 A5 6 A6 7 A7 8 A8 9 V_{CCA} 2 GND 11 V_{CCB} 19 B1 20 B2 18 B3 17 B4 16 B5 15 B6 14 B7 13 B8 12

0.1uF OE 10 A1 1 A2 3 A3 4 A4 5 A5 6 A6 7 A7 8 A8 9 V_{CCA} 2 GND 11 V_{CCB} 19 B1 20 B2 18 B3 17 B4 16 B5 15 B6 14 B7 13 B8 12 U9 TXB0108PW

0.1uF H4 MountingHole H3 MountingHole H2 MountingHole H1 MountingHole

Id: 1/1 Title: File: AlexJ_bz_ArduinoGigaShield.kicad_sch Sheet: /

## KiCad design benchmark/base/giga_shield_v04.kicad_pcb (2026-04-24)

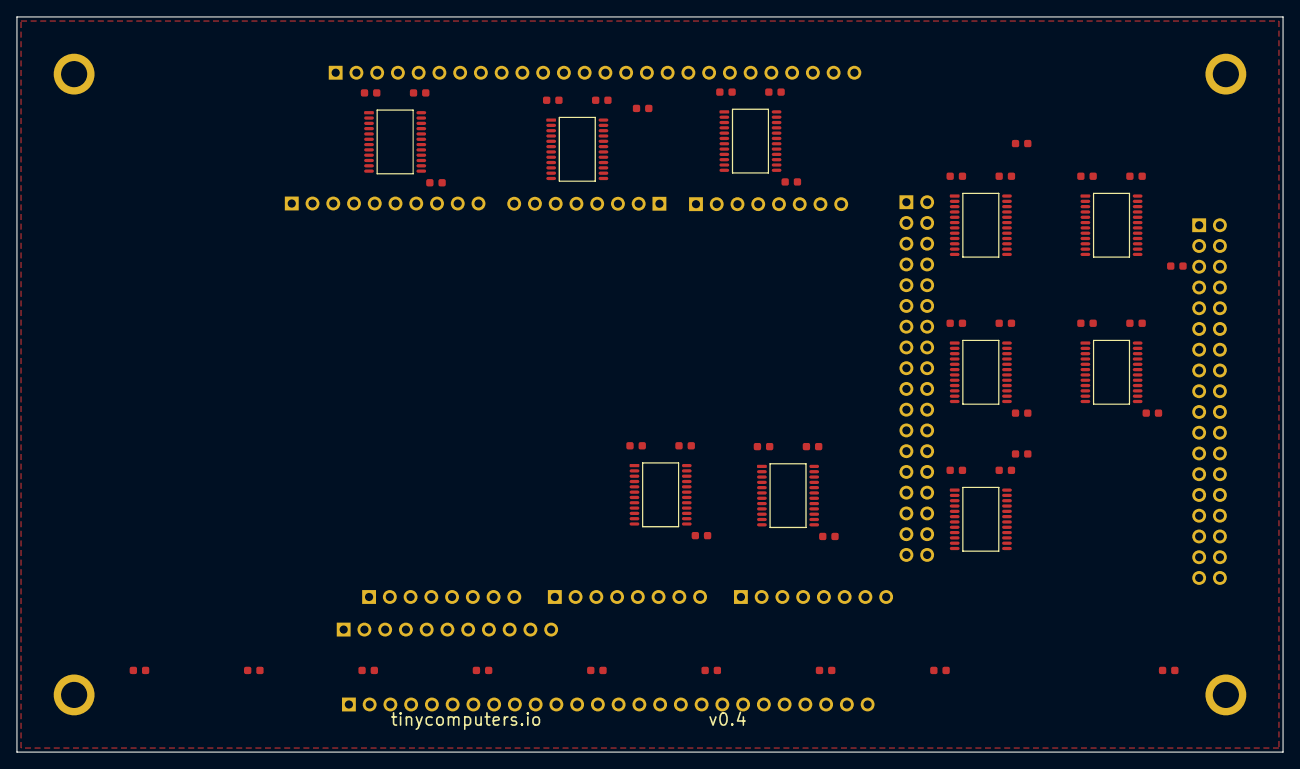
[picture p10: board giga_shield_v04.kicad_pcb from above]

Board: 2 copper layers, 155.0 x 90.0 mm, 64 parts (0 on the bottom side), 161 nets, no tracks yet.

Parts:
C1, C2, C3, C4, C5, C6, C7, C8, C9, C10, C11, C12, C13, C14, C15, C16, C17, C18, C19, C20, C21, C22, C23, C24, C25, C26, C27, C28, C29: 0.1uF; R_0603_1608Metric
H1, H2, H3, H4: MountingHole; MountingHole_3.2mm_M3
J1, J3, J4, J6, J7: Conn_01x08; Connector_PinHeader_1x08_P2.54mm_Vertical
J2: Conn_01x10; Connector_PinHeader_1x10_P2.54mm_Vertical
J5: J_ANALOG; Connector_PinHeader_1x26_P2.54mm_Vertical
J8: J_DIGITAL; Connector_PinHeader_1x26_P2.54mm_Vertical
J9: JSIDE; Connector_PinHeader_2x18_P2.54mm_Vertical
J10: JSIDE_5V; Connector_PinHeader_2x18_P2.54mm_Vertical
J11: DIR_CTRL; Connector_PinHeader_1x11_P2.54mm_Vertical
R1, R2, R3, R4, R5, R6, R7, R8, R9, R10: 10K; R_0603_1608Metric
U1, U2, U3, U4, U5, U6, U7, U8, U9, U10: SN74LVC8T245PW; TSSOP-24_4.4x7.8mm_P0.65mm

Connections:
+3V3: C1.1, C3.1, C5.1, C7.1, C9.1, C11.1, C13.1, C15.1, C17.1, C19.1, C21.1, C23.1, C25.1, C27.1, C29.1, J2.2, J2.3, J5.4, J7.5, R10.2, U1.22, U1.23, U2.22, U2.23, U3.22, U3.23, U4.22, U4.23, U5.22, U5.23, U6.22, U6.23, U7.22, U7.23, U8.22, U8.23, U9.22, U9.23, U10.22, U10.23
+5V: C2.1, C4.1, C6.1, C8.1, C10.1, C12.1, C14.1, C16.1, C18.1, C20.1, C22.1, C24.1, C26.1, C28.1, J5.5, J7.7, J9.1, J9.2, J10.1, J10.2, U1.17, U1.24, U2.17, U2.24, U3.17, U3.24, U4.17, U4.24, U5.17, U5.24, U6.17, U6.24, U7.17, U7.24, U8.17, U8.24, U9.17, U9.24, U10.17, U10.24
A0: J5.9, U2.21
A1: J5.10, U2.20
A2: J5.11, U2.19
A3: J5.12, U2.18
A4: J5.13, U2.16
A5: J5.14, U2.15
A6: J5.15, U2.14
A7: J5.16, U2.13
A8: J5.17, U4.21
A9: J5.18, U4.20
A10: J5.19, U4.19
A11: J5.20, U4.18
AREF: J8.3, U1.19
AREF_3V3: J4.3, U1.4
CAN_RX: J5.23, U4.14
CAN_TX: J5.24, U4.13
D0: J6.1, U5.2
D1: J3.8, U3.10
D2: J3.7, U3.9
D3: J3.6, U3.8
D4: J3.5, U3.7
D5: J3.4, U3.5
D6: J3.3, U3.4
D7: J3.2, U3.3
D8: J3.1, U3.2
D9: J4.8, U1.10
D10: J4.7, U1.9
D11: J4.6, U1.8
D12: J4.5, U1.7
D13: J4.4, U1.5
D14: J6.2, U5.3
D15: J6.3, U5.4
D16: J6.4, U5.5
D17: J6.5, U5.7
D18: J6.6, U5.8
D19: J6.7, U5.9
D20: J6.8, U5.10
D21: J7.1, U8.2
D22: J9.3, U6.2
D23: J9.4, U8.3
D24: J9.5, U6.3
D25: J9.6, U8.4
D26: J9.7, U6.4
D27: J9.8, U8.5
D28: J9.9, U6.5
D29: J9.10, U8.7
D30: J9.11, U6.7
D31: J9.12, U8.8
D32: J9.13, U6.8
D33: J9.14, U8.9
D34: J9.15, U6.9
D35: J9.16, U8.10
D36: J9.17, U6.10
D37: J9.18, U9.2
D38: J9.19, U10.2
D39: J9.20, U9.3
D40: J9.21, U9.4
D41: J9.22, U9.5
D42: J9.23, U7.2
D43: J9.24, U7.3
D44: J9.25, U7.4
D45: J9.26, U7.5
D46: J9.27, U7.7
D47: J9.28, U7.8
D48: J9.29, U7.9
D49: J9.30, U7.10
D50: J9.31, U10.3
D51: J9.32, U10.4
D52: J9.33, U10.5
D53: J9.34, U9.7
DAC0: J5.21, U4.16
DAC1: J5.22, U4.15
DIR_U1: J11.1, R1.1, U1.1
DIR_U2: J11.2, R2.1, U2.1
DIR_U3: J11.3, R3.1, U3.1
DIR_U4: J11.4, R4.1, U4.1
DIR_U5: J11.5, R5.1, U5.1
DIR_U6: J11.6, R6.1, U6.1
DIR_U7: J11.7, R7.1, U7.1
DIR_U8: J11.8, R8.1, U8.1
DIR_U9: J11.9, R9.1, U9.1
DIR_U10: J11.10, R10.1, U10.1
GND: C1.2, C2.2, C3.2, C4.2, C5.2, C6.2, C7.2, C8.2, C9.2, C10.2, C11.2, C12.2, C13.2, C14.2, C15.2, C16.2, C17.2, C18.2, C19.2, C20.2, C21.2, C22.2, C23.2, C24.2, C25.2, C26.2, C27.2, C28.2, C29.2, J5.6, J5.7, J7.6, J7.8, J8.4, J9.35, J9.36, J10.35, J10.36, J11.11, R1.2, R2.2, R3.2, R4.2, R5.2, R6.2, R7.2, R8.2, R9.2, U1.6, U1.11, U1.12, U2.6, U2.11, U2.12, U3.6, U3.11, U3.12, U4.6, U4.11, U4.12, U5.6, U5.11, U5.12, U6.6, U6.11, U6.12, U7.6, U7.11, U7.12, U8.6, U8.11, U8.12, U9.6, U9.11, U9.12, U10.6, U10.11, U10.12
IOREF_3V3: J2.4, J5.2
NRST: J2.5, J5.3
PA0: J1.8, U2.10
PA0_C: J2.9, U4.5
PA1_C: J2.8, U4.4
PA2: J8.15, U3.15
PA3: J8.16, U3.14
PA4: J7.2, U4.7
PA5: J7.3, U4.8
PA7: J8.13, U3.18
PA9: J8.17, U3.13
PB0: J1.3, U2.4
PB1: J1.4, U2.5
PB2: J10.28, U7.15
PB4: J8.11, U3.20
PB5: J7.4, U4.9
PB6: J8.1, U1.21
PB7: J8.18, U5.21
PB8: J8.10, U3.21
PB9: J8.9, U1.13
PB11: J8.25, U5.13
PB13: J2.10, U4.10
PC0: J1.7, U2.9
PC2: J1.6, U2.8
PC2_C: J2.6, U4.2
PC3: J1.5, U2.7
PC3_C: J2.7, U4.3
PC4: J1.1, U2.2
PC5: J1.2, U2.3
PC7: J8.20, U5.19
PD5: J8.23, U5.15
PD6: J8.24, U5.14
PD13_5V: J8.12, U3.19
PE4: J10.30, U7.13
PE5: J10.32, U10.19
PE6: J10.21, U9.19
PG7: J10.34, U9.16
PG10: J10.25, U7.19
PG12: J10.5, U6.20
PG13: J10.4, U8.20
PG14: J8.19, U5.20
PH4: J8.26, U8.21
PH6: J8.5, U1.18
PH12: J8.2, U1.20
PH13: J8.21, U5.18
PH15: J10.27, U7.16
PI9: J8.22, U5.16
PI10: J10.24, U7.20
PI11: J10.31, U10.20
PI13: J10.26, U7.18
PI14: J10.20, U9.20
PI15: J10.23, U7.21
PJ0: J10.6, U8.19
PJ1: J10.8, U8.18
PJ2: J10.10, U8.16
PJ3: J10.12, U8.15
PJ4: J10.14, U8.14
PJ5: J10.16, U8.13
PJ6: J10.18, U9.21
PJ7: J10.19, U10.21
PJ8: J8.14, U3.16
PJ10: J8.7, U1.15
PJ11: J8.6, U1.16
PJ12: J10.3, U6.21
PJ14: J10.7, U6.19
PJ15: J10.9, U6.18
PK0: J10.29, U7.14
PK1: J8.8, U1.14
PK2: J10.33, U10.18
PK3: J10.11, U6.16
PK4: J10.13, U6.15
PK5: J10.15, U6.14
PK6: J10.17, U6.13
PK7: J10.22, U9.18
SCL1: J4.1, U1.2
SDA1: J4.2, U1.3

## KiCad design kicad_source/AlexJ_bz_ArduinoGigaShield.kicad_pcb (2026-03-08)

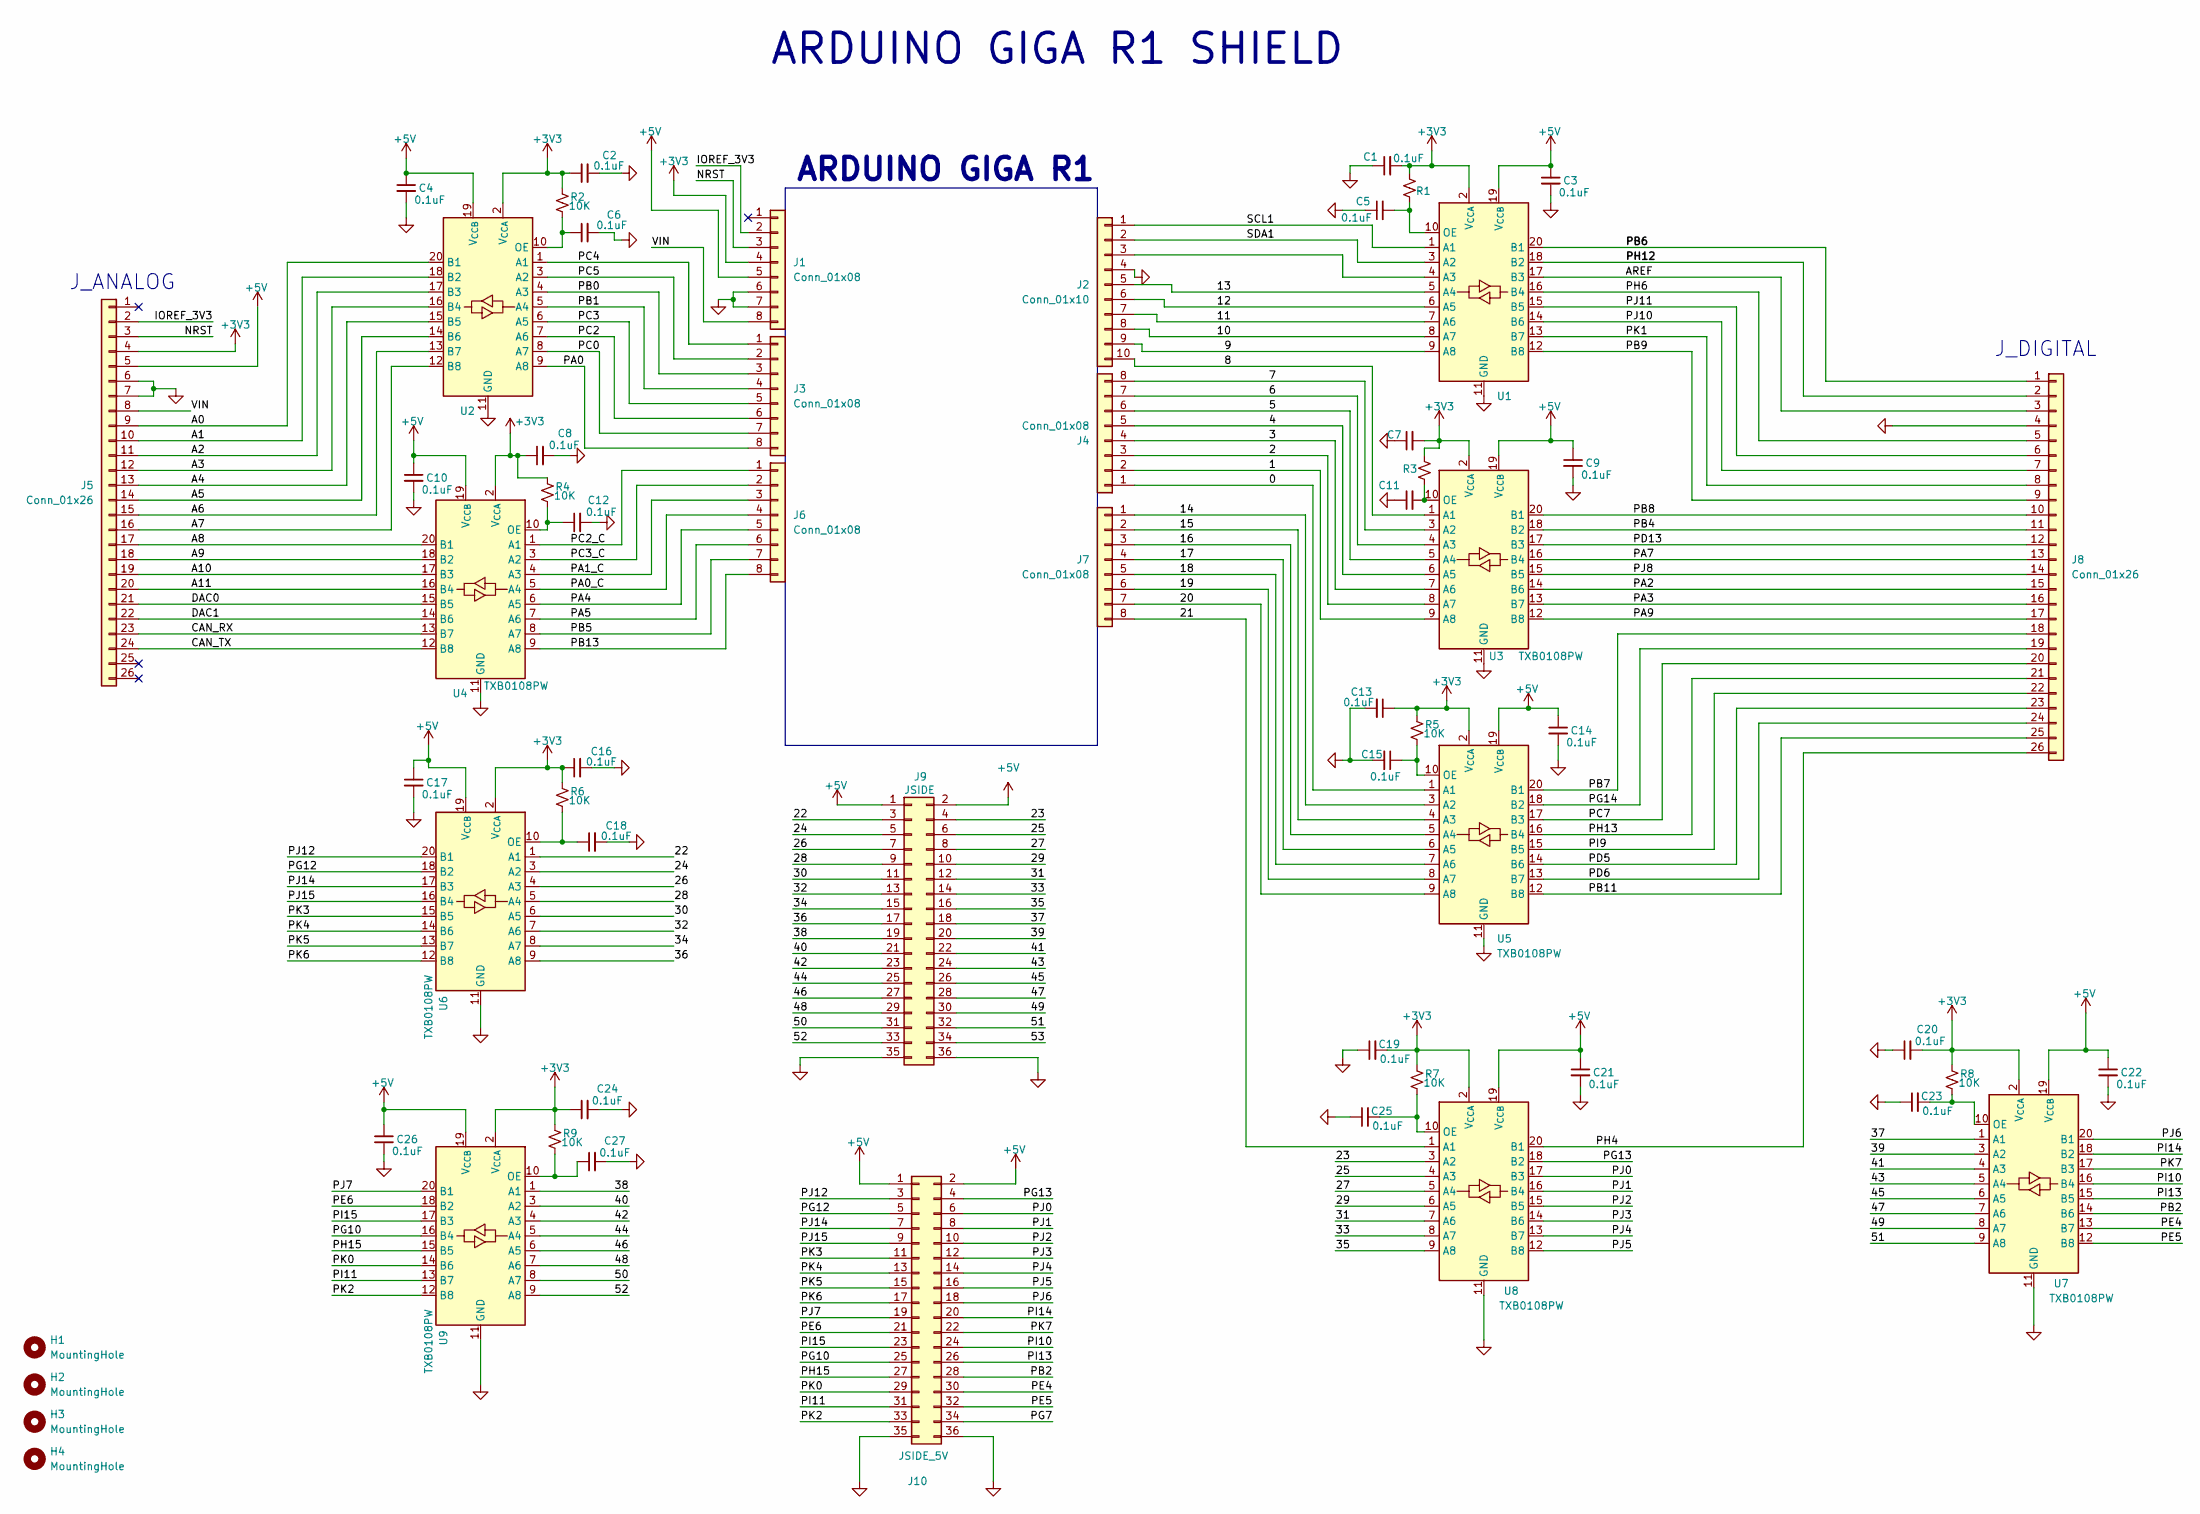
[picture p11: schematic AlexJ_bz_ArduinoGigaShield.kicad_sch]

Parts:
C1, C2, C3, C4, C5, C6, C7, C8, C9, C10, C11, C12, C13, C14, C15, C16, C17, C18, C19, C20, C21, C22, C23, C24, C25, C26, C27: 0.1uF; C_0603_1608Metric
H1, H2, H3, H4: MountingHole; MountingHole_3.2mm_M3
J1, J3, J4, J6, J7: Conn_01x08; PinHeader_1x08_P2.54mm_Vertical
J2: Conn_01x10; PinHeader_1x10_P2.54mm_Vertical
J5, J8: Conn_01x26; PinHeader_1x26_P2.54mm_Vertical
J9: JSIDE; PinHeader_2x18_P2.54mm_Vertical
J10: JSIDE_5V; PinHeader_2x18_P2.54mm_Vertical
R1, R2, R3, R4, R5, R6, R7, R8, R9: 10K; R_0603_1608Metric
U1, U2, U3, U4, U5, U6, U7, U8, U9: TXB0108PW; TSSOP-20_4.4x6.5mm_P0.65mm

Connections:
+3V3: C1.2, C2.1, C7.2, C8.1, C13.1, C16.1, C19.2, C20.2, C24.1, J1.4, J5.4, R1.1, R2.1, R3.1, R4.1, R5.1, R6.1, R7.1, R8.1, R9.1, U1.2 (V_{CCA}), U2.2 (V_{CCA}), U3.2 (V_{CCA}), U4.2 (V_{CCA}), U5.2 (V_{CCA}), U6.2 (V_{CCA}), U7.2 (V_{CCA}), U8.2 (V_{CCA}), U9.2 (V_{CCA})
+5V: C3.1, C4.1, C9.1, C10.1, C14.1, C17.1, C21.1, C22.1, C26.1, J1.5, J5.5, J9.1, J9.2, J10.1, J10.2, U1.19 (V_{CCB}), U2.19 (V_{CCB}), U3.19 (V_{CCB}), U4.19 (V_{CCB}), U5.19 (V_{CCB}), U6.19 (V_{CCB}), U7.19 (V_{CCB}), U8.19 (V_{CCB}), U9.19 (V_{CCB})
/0: J4.1, U5.1 (A1)
/1: J4.2, U3.9 (A8)
/2: J4.3, U3.8 (A7)
/3: J4.4, U3.7 (A6)
/4: J4.5, U3.6 (A5)
/5: J4.6, U3.5 (A4)
/6: J4.7, U3.4 (A3)
/7: J4.8, U3.3 (A2)
/8: J2.10, U3.1 (A1)
/9: J2.9, U1.9 (A8)
/10: J2.8, U1.8 (A7)
/11: J2.7, U1.7 (A6)
/12: J2.6, U1.6 (A5)
/13: J2.5, U1.5 (A4)
/14: J7.1, U5.3 (A2)
/15: J7.2, U5.4 (A3)
/16: J7.3, U5.5 (A4)
/17: J7.4, U5.6 (A5)
/18: J7.5, U5.7 (A6)
/19: J7.6, U5.8 (A7)
/20: J7.7, U5.9 (A8)
/21: J7.8, U8.1 (A1)
/22: J9.3, U6.1 (A1)
/23: J9.4, U8.3 (A2)
/24: J9.5, U6.3 (A2)
/25: J9.6, U8.4 (A3)
/26: J9.7, U6.4 (A3)
/27: J9.8, U8.5 (A4)
/28: J9.9, U6.5 (A4)
/29: J9.10, U8.6 (A5)
/30: J9.11, U6.6 (A5)
/31: J9.12, U8.7 (A6)
/32: J9.13, U6.7 (A6)
/33: J9.14, U8.8 (A7)
/34: J9.15, U6.8 (A7)
/35: J9.16, U8.9 (A8)
/36: J9.17, U6.9 (A8)
/37: J9.18, U7.1 (A1)
/38: J9.19, U9.1 (A1)
/39: J9.20, U7.3 (A2)
/40: J9.21, U9.3 (A2)
/41: J9.22, U7.4 (A3)
/42: J9.23, U9.4 (A3)
/43: J9.24, U7.5 (A4)
/44: J9.25, U9.5 (A4)
/45: J9.26, U7.6 (A5)
/46: J9.27, U9.6 (A5)
/47: J9.28, U7.7 (A6)
/48: J9.29, U9.7 (A6)
/49: J9.30, U7.8 (A7)
/50: J9.31, U9.8 (A7)
/51: J9.32, U7.9 (A8)
/52: J9.33, U9.9 (A8)
/53: J9.34
/A0: J5.9, U2.20 (B1)
/A1: J5.10, U2.18 (B2)
/A2: J5.11, U2.17 (B3)
/A3: J5.12, U2.16 (B4)
/A4: J5.13, U2.15 (B5)
/A5: J5.14, U2.14 (B6)
/A6: J5.15, U2.13 (B7)
/A7: J5.16, U2.12 (B8)
/A8: J5.17, U4.20 (B1)
/A9: J5.18, U4.18 (B2)
/A10: J5.19, U4.17 (B3)
/A11: J5.20, U4.16 (B4)
/AREF: J8.3, U1.17 (B3)
/CAN_RX: J5.23, U4.13 (B7)
/CAN_TX: J5.24, U4.12 (B8)
/DAC0: J5.21, U4.15 (B5)
/DAC1: J5.22, U4.14 (B6)
/IOREF_3V3: J1.2, J5.2
/NRST: J1.3, J5.3
/PA0: J3.8, U2.9 (A8)
/PA0_C: J6.4, U4.5 (A4)
/PA1_C: J6.3, U4.4 (A3)
/PA2: J8.15, U3.14 (B6)
/PA3: J8.16, U3.13 (B7)
/PA4: J6.5, U4.6 (A5)
/PA5: J6.6, U4.7 (A6)
/PA7: J8.13, U3.16 (B4)
/PA9: J8.17, U3.12 (B8)
/PB0: J3.3, U2.4 (A3)
/PB1: J3.4, U2.5 (A4)
/PB2: J10.28, U7.14 (B6)
/PB4: J8.11, U3.18 (B2)
/PB5: J6.7, U4.8 (A7)
/PB6: J8.1, U1.20 (B1)
/PB7: J8.18, U5.20 (B1)
/PB8: J8.10, U3.20 (B1)
/PB9: J8.9, U1.12 (B8)
/PB11: J8.25, U5.12 (B8)
/PB13: J6.8, U4.9 (A8)
/PC0: J3.7, U2.8 (A7)
/PC2: J3.6, U2.7 (A6)
/PC2_C: J6.1, U4.1 (A1)
/PC3: J3.5, U2.6 (A5)
/PC3_C: J6.2, U4.3 (A2)
/PC4: J3.1, U2.1 (A1)
/PC5: J3.2, U2.3 (A2)
/PC7: J8.20, U5.17 (B3)
/PD5: J8.23, U5.14 (B6)
/PD6: J8.24, U5.13 (B7)
/PD13: J8.12, U3.17 (B3)
/PE4: J10.30, U7.13 (B7)
/PE5: J10.32, U7.12 (B8)
/PE6: J10.21, U9.18 (B2)
/PG7: J10.34
/PG10: J10.25, U9.16 (B4)
/PG12: J10.5, U6.18 (B2)
/PG13: J10.4, U8.18 (B2)
/PG14: J8.19, U5.18 (B2)
/PH4: J8.26, U8.20 (B1)
/PH6: J8.5, U1.16 (B4)
/PH12: J8.2, U1.18 (B2)
/PH13: J8.21, U5.16 (B4)
/PH15: J10.27, U9.15 (B5)
/PI9: J8.22, U5.15 (B5)
/PI10: J10.24, U7.16 (B4)
/PI11: J10.31, U9.13 (B7)
/PI13: J10.26, U7.15 (B5)
/PI14: J10.20, U7.18 (B2)
/PI15: J10.23, U9.17 (B3)
/PJ0: J10.6, U8.17 (B3)
/PJ1: J10.8, U8.16 (B4)
/PJ2: J10.10, U8.15 (B5)
/PJ3: J10.12, U8.14 (B6)
/PJ4: J10.14, U8.13 (B7)
/PJ5: J10.16, U8.12 (B8)
/PJ6: J10.18, U7.20 (B1)
/PJ7: J10.19, U9.20 (B1)
/PJ8: J8.14, U3.15 (B5)
/PJ10: J8.7, U1.14 (B6)
/PJ11: J8.6, U1.15 (B5)
/PJ12: J10.3, U6.20 (B1)
/PJ14: J10.7, U6.17 (B3)
/PJ15: J10.9, U6.16 (B4)
/PK0: J10.29, U9.14 (B6)
/PK1: J8.8, U1.13 (B7)
/PK2: J10.33, U9.12 (B8)
/PK3: J10.11, U6.15 (B5)
/PK4: J10.13, U6.14 (B6)
/PK5: J10.15, U6.13 (B7)
/PK6: J10.17, U6.12 (B8)
/PK7: J10.22, U7.17 (B3)
/SCL1: J2.1, U1.1 (A1)
/SDA1: J2.2, U1.3 (A2)
/VIN: J1.8, J5.8
GND: C1.1, C2.2, C3.2, C4.2, C5.1, C6.2, C7.1, C8.2, C9.2, C10.2, C11.1, C12.2, C13.2, C14.2, C15.2, C16.2, C17.2, C18.2, C19.1, C20.1, C21.2, C22.2, C23.1, C24.2, C25.1, C26.2, C27.2, J1.6, J1.7, J2.4, J5.6, J5.7, J8.4, J9.35, J9.36, J10.35, J10.36, U1.11 (GND), U2.11 (GND), U3.11 (GND), U4.11 (GND), U5.11 (GND), U6.11 (GND), U7.11 (GND), U8.11 (GND), U9.11 (GND)
unnamed: J2.3, U1.4 (A3)
unnamed: C5.2, R1.2, U1.10 (OE)
unnamed: C6.1, R2.2, U2.10 (OE)
unnamed: C11.2, R3.2, U3.10 (OE)
unnamed: C12.1, R4.2, U4.10 (OE)
unnamed: C15.1, R5.2, U5.10 (OE)
unnamed: C18.1, R6.2, U6.10 (OE)
unnamed: C23.2, R8.2, U7.10 (OE)
unnamed: C25.2, R7.2, U8.10 (OE)
unnamed: C27.1, R9.2, U9.10 (OE)

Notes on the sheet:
J_ANALOG
ARDUINO GIGA R1 SHIELD
J_DIGITAL
ARDUINO GIGA R1

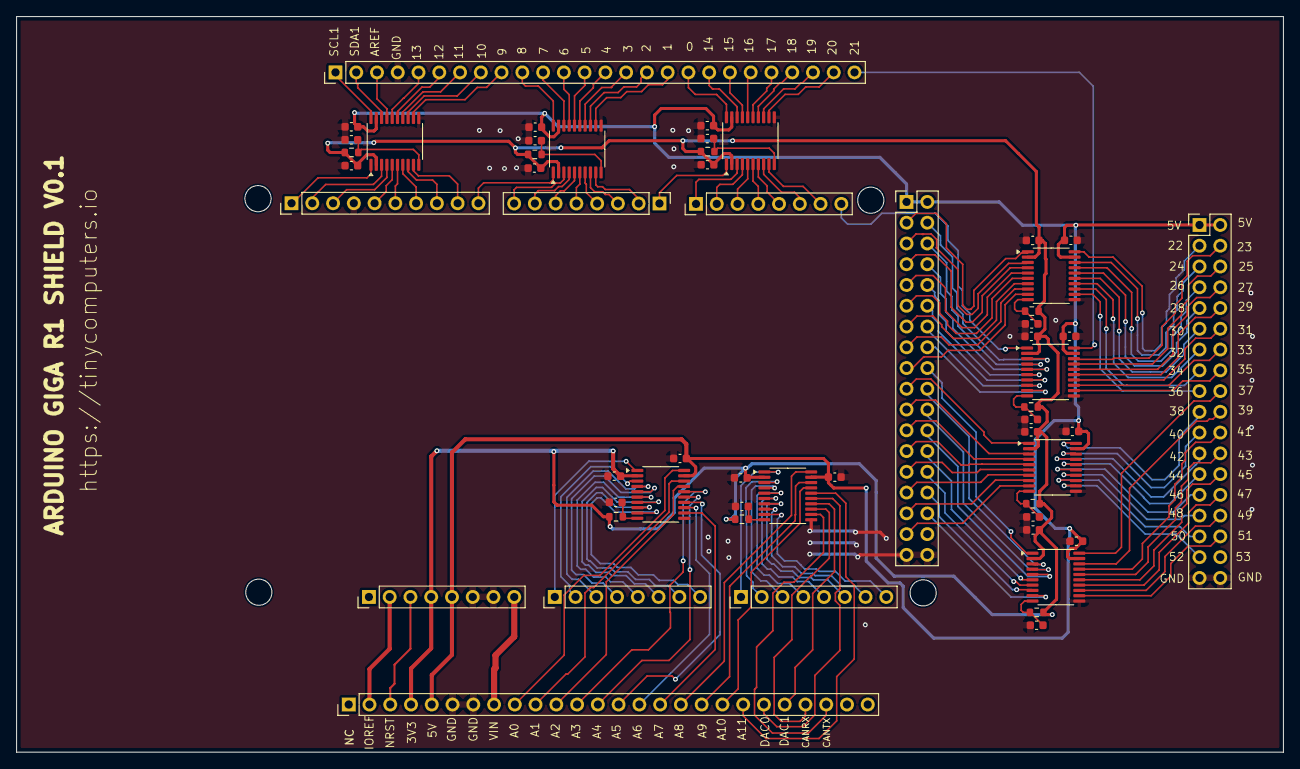
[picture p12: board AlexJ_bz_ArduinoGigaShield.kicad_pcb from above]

Board: 2 copper layers, 155.0 x 90.0 mm, 59 parts (0 on the bottom side), 159 nets.

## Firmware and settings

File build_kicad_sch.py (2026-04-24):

#!/usr/bin/env python3
"""
Generate a KiCad 6+ .kicad_sch schematic for the GigaShield v0.4.

Uses net labels on every pin — no explicit wires needed.
KiCad matches labels by name to form nets.
"""

import uuid
import sys

def uid():
    return str(uuid.uuid4())

# SN74LVC8T245 pin definitions (matches datasheet)
SN74_PINS = [
    (1,  'DIR',  'input'),
    (2,  'A1',   'bidirectional'),
    (3,  'A2',   'bidirectional'),
    (4,  'A3',   'bidirectional'),
    (5,  'A4',   'bidirectional'),
    (6,  'GND',  'power_in'),
    (7,  'A5',   'bidirectional'),
    (8,  'A6',   'bidirectional'),
    (9,  'A7',   'bidirectional'),
    (10, 'A8',   'bidirectional'),
    (11, 'OE',   'input'),
    (12, 'GND',  'power_in'),
    (13, 'B8',   'bidirectional'),
    (14, 'B7',   'bidirectional'),
    (15, 'B6',   'bidirectional'),
    (16, 'B5',   'bidirectional'),
    (17, 'VCCB', 'power_in'),
    (18, 'B4',   'bidirectional'),
    (19, 'B3',   'bidirectional'),
    (20, 'B2',   'bidirectional'),
    (21, 'B1',   'bidirectional'),
    (22, 'VCCA', 'power_in'),
    (23, 'VCCA', 'power_in'),
    (24, 'VCCB', 'power_in'),
]

SHIFTER_NETS = {
    'U1': {
        'a': ['SCL1', 'SDA1', 'AREF_3V3', 'D13', 'D12', 'D11', 'D10', 'D9'],
        'b': ['PB6', 'PH12', 'AREF', 'PH6', 'PJ11', 'PJ10', 'PK1', 'PB9'],
        'dir_net': 'DIR_U1',
    },
    'U2': {
        'a': ['PC4', 'PC5', 'PB0', 'PB1', 'PC3', 'PC2', 'PC0', 'PA0'],
        'b': ['A0', 'A1', 'A2', 'A3', 'A4', 'A5', 'A6', 'A7'],
        'dir_net': 'DIR_U2',
    },
    'U3': {
        'a': ['D8', 'D7', 'D6', 'D5', 'D4', 'D3', 'D2', 'D1'],
        'b': ['PB8', 'PB4', 'PD13_5V', 'PA7', 'PJ8', 'PA2', 'PA3', 'PA9'],
        'dir_net': 'DIR_U3',
    },
    'U4': {
        'a': ['PC2_C', 'PC3_C', 'PA1_C', 'PA0_C', 'PA4', 'PA5', 'PB5', 'PB13'],
        'b': ['A8', 'A9', 'A10', 'A11', 'DAC0', 'DAC1', 'CAN_RX', 'CAN_TX'],
        'dir_net': 'DIR_U4',
    },
    'U5': {
        'a': ['D0', 'D14', 'D15', 'D16', 'D17', 'D18', 'D19', 'D20'],
        'b': ['PB7', 'PG14', 'PC7', 'PH13', 'PI9', 'PD5', 'PD6', 'PB11'],
        'dir_net': 'DIR_U5',
    },
    'U6': {
        'a': ['D22', 'D24', 'D26', 'D28', 'D30', 'D32', 'D34', 'D36'],
        'b': ['PJ12', 'PG12', 'PJ14', 'PJ15', 'PK3', 'PK4', 'PK5', 'PK6'],
        'dir_net': 'DIR_U6',
    },
    'U7': {
        'a': ['D42', 'D43', 'D44', 'D45', 'D46', 'D47', 'D48', 'D49'],
        'b': ['PI15', 'PI10', 'PG10', 'PI13', 'PH15', 'PB2', 'PK0', 'PE4'],
        'dir_net': 'DIR_U7',
    },
    'U8': {
        'a': ['D21', 'D23', 'D25', 'D27', 'D29', 'D31', 'D33', 'D35'],
        'b': ['PH4', 'PG13', 'PJ0', 'PJ1', 'PJ2', 'PJ3', 'PJ4', 'PJ5'],
        'dir_net': 'DIR_U8',
    },
    'U9': {
        'a': ['D37', 'D39', 'D40', 'D41', 'D53', 'NC_U9A6', 'NC_U9A7', 'NC_U9A8'],
        'b': ['PJ6', 'PI14', 'PE6', 'PK7', 'PG7', 'NC_U9B6', 'NC_U9B7', 'NC_U9B8'],
        'dir_net': 'DIR_U9',
    },
    'U10': {
        'a': ['D38', 'D50', 'D51', 'D52', 'NC_U10A5', 'NC_U10A6', 'NC_U10A7', 'NC_U10A8'],
        'b': ['PJ7', 'PI11', 'PE5', 'PK2', 'NC_U10B5', 'NC_U10B6', 'NC_U10B7', 'NC_U10B8'],
        'dir_net': 'DIR_U10',
    },
}

# Connector pin lists
CONNECTORS = {
    'J1':  {'pins': ['PC4', 'PC5', 'PB0', 'PB1', 'PC3', 'PC2', 'PC0', 'PA0'], 'val': '1x08 Analog 3.3V'},
    'J2':  {'pins': ['VIN', '+3V3', '+3V3', 'IOREF_3V3', 'NRST', 'PC2_C', 'PC3_C', 'PA1_C', 'PA0_C', 'PB13'], 'val': '1x10 Power 3.3V'},
    'J3':  {'pins': ['D8', 'D7', 'D6', 'D5', 'D4', 'D3', 'D2', 'D1'], 'val': '1x08 Digital 3.3V'},
    'J4':  {'pins': ['SCL1', 'SDA1', 'AREF_3V3', 'D13', 'D12', 'D11', 'D10', 'D9'], 'val': '1x08 Digital 3.3V'},
    'J5':  {'pins': ['NC', 'IOREF_3V3', 'NRST', '+3V3', '+5V', 'GND', 'GND', 'VIN',
                     'A0', 'A1', 'A2', 'A3', 'A4', 'A5', 'A6', 'A7',
                     'A8', 'A9', 'A10', 'A11', 'DAC0', 'DAC1', 'CAN_RX', 'CAN_TX', 'NC', 'NC'], 'val': '1x26 Analog 5V'},
    'J6':  {'pins': ['D0', 'D14', 'D15', 'D16', 'D17', 'D18', 'D19', 'D20'], 'val': '1x08 Digital 3.3V'},
    'J7':  {'pins': ['D21', 'PA4', 'PA5', 'PB5', '+3V3', 'GND', '+5V', 'GND'], 'val': '1x08 Misc 3.3V'},
    'J8':  {'pins': ['PB6', 'PH12', 'AREF', 'GND',
                     'PH6', 'PJ11', 'PJ10', 'PK1', 'PB9',
                     'PB8', 'PB4', 'PD13_5V', 'PA7', 'PJ8', 'PA2', 'PA3', 'PA9',
                     'PB7', 'PG14', 'PC7', 'PH13', 'PI9', 'PD5', 'PD6', 'PB11', 'PH4'], 'val': '1x26 Digital 5V'},
    'J9':  {'pins': ['+5V', '+5V',
                     'D22', 'D23', 'D24', 'D25', 'D26', 'D27', 'D28', 'D29',
                     'D30', 'D31', 'D32', 'D33', 'D34', 'D35', 'D36', 'D37',
                     'D38', 'D39', 'D40', 'D41', 'D42', 'D43', 'D44', 'D45',
                     'D46', 'D47', 'D48', 'D49', 'D50', 'D51', 'D52', 'D53',
                     'GND', 'GND'], 'val': '2x18 Side 3.3V'},
    'J10': {'pins': ['+5V', '+5V',
                     'PJ12', 'PG13', 'PG12', 'PJ0', 'PJ14', 'PJ1', 'PJ15', 'PJ2',
                     'PK3', 'PJ3', 'PK4', 'PJ4', 'PK5', 'PJ5', 'PK6', 'PJ6',
                     'PJ7', 'PI14', 'PE6', 'PK7', 'PI15', 'PI10', 'PG10', 'PI13',
                     'PH15', 'PB2', 'PK0', 'PE4', 'PI11', 'PE5', 'PK2', 'PG7',
                     'GND', 'GND'], 'val': '2x18 Side 5V'},
    'J11': {'pins': ['DIR_U1', 'DIR_U2', 'DIR_U3', 'DIR_U4', 'DIR_U5',
                     'DIR_U6', 'DIR_U7', 'DIR_U8', 'DIR_U9', 'DIR_U10', 'GND'], 'val': '1x11 DIR Control'},
}

POWER_NETS = {'+3V3', '+5V', 'GND'}


def get_shifter_net(uref, pin_num):
    """Get the net name for a given shifter pin."""
    sn = SHIFTER_NETS[uref]
    pin_map = {
        1: sn['dir_net'],
        2: sn['a'][0], 3: sn['a'][1], 4: sn['a'][2], 5: sn['a'][3],
        6: 'GND',
        7: sn['a'][4], 8: sn['a'][5], 9: sn['a'][6], 10: sn['a'][7],
        11: 'GND', 12: 'GND',
        13: sn['b'][7], 14: sn['b'][6], 15: sn['b'][5], 16: sn['b'][4],
        17: '+5V',
        18: sn['b'][3], 19: sn['b'][2], 20: sn['b'][1], 21: sn['b'][0],
        22: '+3V3', 23: '+3V3', 24: '+5V',
    }
    return pin_map.get(pin_num, '')
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

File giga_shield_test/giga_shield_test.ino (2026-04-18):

// GigaShield v0.2 — Z80 RetroShield Profiling/Test Sketch
// Tests level shifter operation and Z80 bus timing
//
// Wiring:
//   J11-7  (DIR_U7)  → A0 (data bus direction)
//   J11-10 (DIR_U10) → +3.3V (control outputs always Giga→Z80)
//   J11-11 (GND)     → Giga GND
//   All other J11 pins float to pulldown (B→A default)

// ── DIR control ──
#define DIR_DATA    A0    // J11-7: LOW = Z80→Giga, HIGH = Giga→Z80

// ── Z80 control outputs (U10, always Giga → Z80) ──
#define Z80_CLK     52
#define Z80_RESET   38
#define Z80_INT     50
#define Z80_NMI     51

// ── Z80 control inputs (U9, always Z80 → Giga) ──
// Verify these match your RetroShield wiring
#define Z80_M1      37
#define Z80_RD      39
#define Z80_WR      40
#define Z80_MREQ    41
#define Z80_IORQ    53

// ── Z80 data bus (U7, bidirectional) ──
const uint8_t DATA_PINS[8] = {42, 43, 44, 45, 46, 47, 48, 49};  // D0–D7

// ── Timing ──
static unsigned long cycleCount = 0;
static unsigned long lastReport = 0;
static const unsigned long REPORT_INTERVAL_MS = 2000;

// Clock generation via timer or manual toggle
static bool manualClock = true;
static unsigned long clkHalfPeriodUs = 500;  // 1 kHz default

void setDataDir(bool gigaDrives) {
  digitalWrite(DIR_DATA, gigaDrives ? HIGH : LOW);
  if (gigaDrives) {
    for (int i = 0; i < 8; i++) pinMode(DATA_PINS[i], OUTPUT);
  } else {
    for (int i = 0; i < 8; i++) pinMode(DATA_PINS[i], INPUT);
  }
}

uint8_t readDataBus() {
  uint8_t val = 0;
  for (int i = 0; i < 8; i++) {
    if (digitalRead(DATA_PINS[i])) val |= (1 << i);
  }
  return val;
}

void writeDataBus(uint8_t val) {
  for (int i = 0; i < 8; i++) {
    digitalWrite(DATA_PINS[i], (val >> i) & 1);
  }
}

void printBusState() {
  Serial.print("CTRL: M1=");
  Serial.print(digitalRead(Z80_M1));
  Serial.print(" RD=");
  Serial.print(digitalRead(Z80_RD));
  Serial.print(" WR=");
  Serial.print(digitalRead(Z80_WR));
  Serial.print(" MREQ=");
  Serial.print(digitalRead(Z80_MREQ));
  Serial.print(" IORQ=");
  Serial.print(digitalRead(Z80_IORQ));

  setDataDir(false);  // Z80→Giga to read
  Serial.print("  DATA=0x");
  Serial.println(readDataBus(), HEX);
}

// ── Test 1: Shifter loopback ──
// Writes a pattern on the data bus and reads it back.
// Requires the 5V side to be looped back (or a Z80 that echoes).
// Without loopback, verifies Giga→shifter output toggles correctly.
void testShifterOutput() {
  Serial.println("\n=== Test 1: Data bus output ===");
  setDataDir(true);  // Giga drives

  uint8_t patterns[] = {0x00, 0xFF, 0xAA, 0x55, 0x01, 0x80, 0xDE, 0xAD};
  for (uint8_t pat : patterns) {
    writeDataBus(pat);
    delayMicroseconds(10);
    Serial.print("  Wrote: 0x");
    Serial.println(pat, HEX);
  }

  setDataDir(false);  // back to read mode
  Serial.println("  Output test complete — verify with scope/logic analyzer on 5V side");
}

// ── Test 2: Control output verification ──
void testControlOutputs() {
  Serial.println("\n=== Test 2: Control outputs (CLK, RESET, INT, NMI) ===");

  // Toggle each control line
  struct { const char* name; int pin; } signals[] = {
    {"RESET", Z80_RESET}, {"INT", Z80_INT}, {"NMI", Z80_NMI}, {"CLK", Z80_CLK}
  };

  for (auto& sig : signals) {
    digitalWrite(sig.pin, HIGH);
    delayMicroseconds(100);
    digitalWrite(sig.pin, LOW);
    delayMicroseconds(100);
    Serial.print("  Toggled ");
    Serial.println(sig.name);
  }
  Serial.println("  Verify transitions on 5V side with scope");
}

// ── Test 3: Control input read ──
void testControlInputs() {
  Serial.println("\n=== Test 3: Control inputs (active-low Z80 signals) ===");
  Serial.print("  /M1=");    Serial.print(digitalRead(Z80_M1));
  Serial.print("  /RD=");    Serial.print(digitalRead(Z80_RD));
  Serial.print("  /WR=");    Serial.print(digitalRead(Z80_WR));
  Serial.print("  /MREQ=");  Serial.print(digitalRead(Z80_MREQ));
  Serial.print("  /IORQ=");  Serial.println(digitalRead(Z80_IORQ));
  Serial.println("  With no Z80 clock, all should read HIGH (inactive)");
}

// ── Test 4: Clock + bus profiling ──
void testClockAndProfile() {
  Serial.println("\n=== Test 4: Clock generation + bus profiling ===");
  Serial.print("  Running 100 clock cycles at ");
  Serial.print(1000000UL / (2 * clkHalfPeriodUs));
  Serial.println(" Hz...");

  setDataDir(false);  // Z80→Giga (read mode)

  unsigned long t0 = micros();
  int mreqCount = 0;
  bool prevMreq = HIGH;

  for (int i = 0; i < 100; i++) {
    digitalWrite(Z80_CLK, HIGH);
    delayMicroseconds(clkHalfPeriodUs);

    // Sample on falling edge (Z80 convention)
    bool mreq = digitalRead(Z80_MREQ);
    if (prevMreq == HIGH && mreq == LOW) {
      mreqCount++;
    }
    prevMreq = mreq;

    digitalWrite(Z80_CLK, LOW);
    delayMicroseconds(clkHalfPeriodUs);
  }

  unsigned long elapsed = micros() - t0;

  Serial.print("  Elapsed: ");
  Serial.print(elapsed);
  Serial.println(" us");
  Serial.print("  Avg cycle: ");
  Serial.print(elapsed / 100);
  Serial.println(" us");
  Serial.print("  /MREQ falling edges seen: ");
  Serial.println(mreqCount);

  if (mreqCount == 0) {
    Serial.println("  ⚠ No MREQ activity — Z80 may not be running");
    Serial.println("    Check: RESET released? CLK reaching Z80? U10 DIR = 3.3V?");
  }
}

// ── Test 5: Z80 boot + memory read capture ──
void testZ80Boot() {
  Serial.println("\n=== Test 5: Z80 boot — first 16 bus cycles ===");

  // Hold reset
  digitalWrite(Z80_RESET, LOW);
  delay(10);

  // Ensure data bus readable
  setDataDir(false);

  // Release reset
  digitalWrite(Z80_RESET, HIGH);
  Serial.println("  RESET released");

  for (int cycle = 0; cycle < 16; cycle++) {
    digitalWrite(Z80_CLK, HIGH);
    delayMicroseconds(clkHalfPeriodUs);

    // Sample on falling edge
    digitalWrite(Z80_CLK, LOW);
    delayMicroseconds(1);  // setup time

    bool m1   = digitalRead(Z80_M1);
    bool rd   = digitalRead(Z80_RD);
    bool mreq = digitalRead(Z80_MREQ);
    uint8_t data = readDataBus();

    Serial.print("  T");
    if (cycle < 10) Serial.print("0");
    Serial.print(cycle);
    Serial.print(": /M1=");
    Serial.print(m1);
    Serial.print(" /RD=");
    Serial.print(rd);
    Serial.print(" /MREQ=");
    Serial.print(mreq);
    Serial.print(" DATA=0x");
    if (data < 0x10) Serial.print("0");
    Serial.println(data, HEX);

    delayMicroseconds(clkHalfPeriodUs);
  }

  // Hold reset again
  digitalWrite(Z80_RESET, LOW);
  Serial.println("  RESET asserted — Z80 halted");
}

// ── Test 6: DIR toggle speed ──
void testDirToggleSpeed() {
  Serial.println("\n=== Test 6: DIR toggle speed (U7) ===");

  unsigned long t0 = micros();
  for (int i = 0; i < 10000; i++) {
    digitalWrite(DIR_DATA, HIGH);
    digitalWrite(DIR_DATA, LOW);
  }
  unsigned long elapsed = micros() - t0;

  Serial.print("  10000 DIR toggles in ");
  Serial.print(elapsed);
  Serial.print(" us (");
  Serial.print(elapsed / 10);
  Serial.println(" ns per toggle)");
}

void setup() {
  Serial.begin(115200);
  while (!Serial && millis() < 3000);

  Serial.println("GigaShield v0.2 — Z80 RetroShield Test");
  Serial.println("=======================================");

  // DIR control
  pinMode(DIR_DATA, OUTPUT);
  digitalWrite(DIR_DATA, LOW);  // default: Z80→Giga

  // Control outputs
  pinMode(Z80_CLK, OUTPUT);
  pinMode(Z80_RESET, OUTPUT);
  pinMode(Z80_INT, OUTPUT);
  pinMode(Z80_NMI, OUTPUT);

  // Hold Z80 in reset, INT/NMI inactive (active-low, so HIGH = inactive)
  digitalWrite(Z80_RESET, LOW);
  digitalWrite(Z80_INT, HIGH);
  digitalWrite(Z80_NMI, HIGH);
  digitalWrite(Z80_CLK, LOW);

  // Control inputs (active-low from Z80)
  pinMode(Z80_M1, INPUT_PULLUP);
  pinMode(Z80_RD, INPUT_PULLUP);
  pinMode(Z80_WR, INPUT_PULLUP);
  pinMode(Z80_MREQ, INPUT_PULLUP);
  pinMode(Z80_IORQ, INPUT_PULLUP);

  // Data bus starts as input
  for (int i = 0; i < 8; i++) pinMode(DATA_PINS[i], INPUT);

  Serial.println("\nCommands:");
  Serial.println("  1 — Shifter output test");
  Serial.println("  2 — Control output toggle");
  Serial.println("  3 — Control input read");
  Serial.println("  4 — Clock + bus profiling (100 cycles)");
  Serial.println("  5 — Z80 boot capture (16 cycles)");
  Serial.println("  6 — DIR toggle speed");
  Serial.println("  s — Print current bus state");
  Serial.println("  f — Set clock frequency (enter Hz)");
  Serial.println();
}

void loop() {
  if (Serial.available()) {
    char c = Serial.read();
    switch (c) {
      case '1': testShifterOutput(); break;
      case '2': testControlOutputs(); break;
      case '3': testControlInputs(); break;
      case '4': testClockAndProfile(); break;
      case '5': testZ80Boot(); break;
      case '6': testDirToggleSpeed(); break;
      case 's': printBusState(); break;
      case 'f': {
        Serial.print("Enter frequency (Hz): ");
        while (!Serial.available());
        long freq = Serial.parseInt();
        if (freq > 0 && freq <= 1000000) {
          clkHalfPeriodUs = 500000UL / freq;
          if (clkHalfPeriodUs < 1) clkHalfPeriodUs = 1;
          Serial.print("Clock set to ");
          Serial.print(freq);
          Serial.print(" Hz (half-period ");
          Serial.print(clkHalfPeriodUs);
          Serial.println(" us)");
        } else {
          Serial.println("Invalid — range: 1–1000000 Hz");
        }
        break;
      }
    }
  }
}

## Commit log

2026-03-08 Initial commit: Arduino Giga R1 Shield with SN74LVC8T245PW driven level shifters
    Redesigned from original TXB0108PW auto-sensing design to fix Z80 bus
    tri-state blindness. 9x SN74LVC8T245PW, 155x90mm 2-layer board, fully
    routed with 1843 traces/158 vias. Includes build script, gerbers, BOM,
    centroid, and original KiCad source files for reference.
    [AlexJ_bz_ArduinoGigaShield.csv, AlexJ_bz_ArduinoGigaShield.kicad_pcb, AlexJ_bz_ArduinoGigaShield.kicad_sch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]
2026-03-08 Move original KiCad source files into kicad_source/ subdirectory
    [AlexJ_bz_ArduinoGigaShield.csv, AlexJ_bz_ArduinoGigaShield.kicad_pcb, AlexJ_bz_ArduinoGigaShield.kicad_sch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]
2026-03-08 Remove loose gerber files from tracking, already in production zip
    [giga_shield.bottom.copper.none.6.gbr, giga_shield.bottom.mask.none.7.gbr, giga_shield.global.boundary.uroute.5.gbr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]
2026-03-08 Add silkscreen labels for J11 DIR control header pins
    Labels each pin (U1-U9, GND) with rotated text below the header,
    plus a "J11 DIR" title above. Includes full pcb-rnd symbol table
    for text rendering. Regenerated gerbers and renderings.
2026-03-08 Move decoupling caps C19-C27 to clear J5 overlap, add routing video
    Moved extra power decoupling caps from y=85mm to y=80mm so they no
    longer overlap with J5 (1x26 analog header at y=84.17mm). Full
    re-route: 1922 traces, 175 vias. Added routing-traces.mp4.
    [giga_shield.dsn, giga_shield_centroid.csv]
2026-03-08 Move R3 to clear J4 overlap, fix silk labels to Layer 5
    R3 moved from (73.6, 21.2) to (73.6, 11.2) to avoid overlapping
    J4 header pins. Silk text moved from Layer 4 to Layer 5 for proper
    rendering on top side. Re-routed: 1864 traces, 153 vias.
    [giga_shield.dsn, giga_shield_centroid.csv]
2026-03-08 Fix all component overlaps: R3, R6, R8 repositioned, caps respaced
    Comprehensive overlap analysis found 4 conflicts:
    - C5/R3: R3 moved further right (dx +8mm)
    - C15/R6: R6 moved above U6 (dy -10mm) to clear U8 caps
    - C17/R8: R8 moved further right (dx +8mm) to clear U9 caps
    - H2/C19: Extra decoupling caps respaced (start x=15, pitch=14mm)
    Zero overlaps verified. Re-routed: 1964 traces, 182 vias.
    [giga_shield.dsn, giga_shield_centroid.csv]
2026-03-13 Add silkscreen branding, DSN via/rule fixes, re-routed board, drill file
    Add tinycomputers.io and v0.2 text to silkscreen in build script.
    Add via and rule definitions to DSN structure section for Freerouting.
    Updated PCB with new routing from Freerouting v1.9 (2911 traces, 172 vias).
    Regenerated gerbers, board images, and added plated drill file.
    [giga_shield.dsn]
2026-04-18 Fix pin numbering bug and add KiCad build pipeline
    Fix critical zigzag pin ordering bug in pin_header_element that caused
    every signal on 2x18 headers (J9/J10) to land at wrong physical positions.
    Reposition U6-U10 in staggered layout between J9/J10 to eliminate routing
    congestion. Add build_kicad.py for KiCad PCB generation and
    build_kicad_sch.py for schematic generation. Add Arduino test sketch for
    Z80 RetroShield bus profiling. Move R10 and C29 clear of U10. Update
    silkscreen to v0.4.
    [giga_shield.dsn]
2026-04-20 Add v0.4 fab package, R10 pull-up fix, component repositioning
    Fix critical R10 safety issue: changed R10 from pulldown-to-GND to
    pull-up-to-+3V3 so U10 defaults to A→B direction (Giga→Z80) for
    CLK/RESET/INT/NMI. Previously would have driven 5V Z80 outputs into
    3.3V Giga inputs on power-up.
    Reposition U6-U10 in staggered two-column layout between J9/J10 for
    cleaner routing on 4 layers. Move C29 clear of U10 body.
    Fix J11 GND pin netlist entry in pcb-rnd generator.
    Add fabrication_v04.zip with final Gerbers, drill files, BOM, and
    centroid. Passed PCBWay DFM after routing with 0.3mm per-type
    clearance rules.
    [giga_shield.dsn]
2026-04-24 Update .gitignore to exclude build artifacts, local state, and symlinks
    Add patterns for Python venvs, __pycache__, log files, KiCad .kicad_prl
    local-state files, macOS/editor metadata, the .claude/ local tooling
    directory, the tinycomputers.io symlink to a separate project, and
    unzipped fabrication directories that are redundant with their zips.
2026-04-24 Archive v0.3 KiCad sources, gerbers, and renders
    The v0.3 design was the first Claude-assisted redesign. It shipped but
    failed bring-up due to the pin-numbering bug documented in
    'How a Pin Numbering Bug Killed a PCB'. Preserved here as the historical
    record of what was fabricated before the v0.4 respin.
    [giga_shield_v03_final.kicad_pcb]
2026-04-24 Add v0.4 KiCad design, routed PCB, and renders
    The v0.4 respin fixes the pin-numbering bug from v0.3 and the R10
    pull-down direction bug caught during a Claude-assisted audit. Includes
    the post-Freerouting routed kicad_pcb, the DRC report, and top-down and
    isometric renders of the board with copper pour completed.
    [giga_shield_v04.kicad_pcb, giga_shield_v04.kicad_sch, giga_shield_v04_routed.kicad_pcb]
2026-04-24 Add v0.4 routing artifacts and v0.5 intermediate design
    The v0.4.ses is the Freerouting output imported into the final routed
    board. v0.5 was an interim KiCad rework used to post-process gerbers
    when PCBWay flagged annular-ring overlap (fabrication_v05.zip). The
    KiCad-exported DSN and normalized .kicad_pro are part of the
    Freerouting feedback loop.
    [giga_shield_v04_kicad.dsn, giga_shield_v05.dsn, giga_shield_v05.kicad_pcb]
2026-04-24 Add fabrication packages v05 and v06 with PCBWay correspondence
    v05 fixes the first PCBWay DFM question (via annular ring overlap):
    D12/D21/D29/D51 aperture 0.0600" -> 0.0295" (1.524mm -> 0.75mm pad)
    and T11 drill 0.035" -> 0.0157" (0.889mm -> 0.4mm drill), applied as
    post-processing to the v04 gerbers.
    v06 fixes the second PCBWay DFM question (mask/paste aperture mismatch)
    at the source: 0603 cap pad mask aperture bumped from 0.6mm (smaller
    than the 0.9mm copper pad) to 1.0mm, then regenerated from pcb-rnd.
    Includes the component question XLSX PCBWay attached.
    [T-2D32W364146A-component questions.xlsx]
2026-04-24 Add helper scripts for pours, power nets, SES import, and routing batches
    These scripts were used across the v0.4 through v0.6 pipeline:
    - add_gnd.py / add_pours.py / add_power_nets.py: inject GND, +3V3, +5V
    plane fills and power-net assignments into the KiCad PCB after initial
    generation from the Python build script
    - flip_to_bottom.py: helper for mirroring components (experimental)
    - import_ses.py: read a Freerouting .ses back into KiCad
    - route_d15.py / d15_route.txt: single-net route check used to diagnose
    the D15 congestion case
    - shuffle_dsn.py: DSN net reordering experiment
    - run_batch.sh / run_batch_xvfb.sh: parallel Freerouting batch drivers
    used for the pyplacer seed sweep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
    [build_kicad_sch.py]
2026-04-24 Add placement benchmark suite: pyplacer vs Quilter vs manual
    Compares three placement approaches on the v0.4 giga-shield board:
    - base/: unplaced source used as the common input to all placers
    - placement/: manual hand-placement (routes to 100% with Freerouting)
    - quilter/: Quilter.ai Candidate_1 (99.4% routed)
    - pyplacer/: open-source simulated-annealing placer (best seed ~93.8%)
    - freerouting/: the routed comparison artifacts
    pyplacer source is the weekend-grade reference implementation that
    motivated the standalone repo at github.com/ajokela/pyplacer. compare.py
    scores placements by unrouted-net count after a Freerouting pass under
    identical 0.3mm-clearance rules for all three.
    Backs t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
    [giga_shield.dsn, giga_shield_pyplaced.dsn, giga_shield_v04.kicad_pcb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]
2026-04-24 Add ROUTING_NOTES.md: development notes on Freerouting tuning
    Captures the clearance-rule findings from the v0.4 PCBWay DFM saga (the
    121-false-positive DRC episode), the -mp/-oit/-mt Freerouting CLI flags
    that matter for reproducible runs, and the per-type clearance rule
    template that passes PCBWay's automated DFM on a 4-layer dense board.
2026-04-24 Ignore PCBWay order correspondence PDF
